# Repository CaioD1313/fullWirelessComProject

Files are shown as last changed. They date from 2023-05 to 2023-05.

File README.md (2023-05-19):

# fullWirelessComProject
Schematics, PCB, Firmwares, DataSheets, Notes and Documentation of this project.

# Full Wireless Communication Device

This project was developed as part of the interview process for the Firmware Engineer position. The objective was to build a Full Wireless Communication Device capable of sending data over a 100m air gap. The repository contains the following components in the main folder/root directory:

- **Datasheets**: This folder contains the datasheets used for the development of the project.
- **Schematics and PCB files**: The "KiCad Projeto Tractian" folder includes the schematics and PCB files related to the project.
- **Firmware**: The "Firmware_fullWirelessSystem" folder contains the firmware code for the device.
- **Technical Documentation**: The project's complete technical documentation can be found in the root directory as the file "Project's Technical Documentation.pdf".

Feel free to explore the respective folders for more details on each aspect of the project.

**Be aware! The documentation is long and tedious, as every technical document should be. (:**

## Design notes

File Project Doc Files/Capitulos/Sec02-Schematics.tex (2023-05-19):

%%%%%%%%%%%%%%%%%%%%%%%%%%%%%%%%%%%%%%%%%%%%%%
%%%%%%%%          Schematics          %%%%%%%%
%%%%%%%%%%%%%%%%%%%%%%%%%%%%%%%%%%%%%%%%%%%%%%

\section{Circuitry}\label{02Sec:Circuitry}

\subsection{Block Diagram}\label{02Sub:BlockDiagram}

The block diagram of the device on the Figure \ref{02fig:BD} consists of several main components that play essential roles in its operation. 
Here is a brief overview of each of these parts:

\begin{itemize}
    \item Microcontroller (ESP8266EX): The ESP8266EX microcontroller is the central component of the device. It is responsible for 
    controlling all operations and functionalities, including wireless communication via WiFi.
    
    \item Program Memory (MX25R3235F): The program memory is where the device's firmware is stored. 
    % In this project, the MX25R3235F 
    % chip with a capacity of 32Mbit was selected. This memory stores the program that controls the device's operation, allowing it 
    % to perform the desired tasks.

    \item Data Memory (AT25SF081): The data memory is used to store the collected data in the device.
    % For this purpose, the 
    % AT25SF081 chip with a capacity of 8Mbit was chosen. This memory is utilized to store the temperature information collected 
    % by the sensor, enabling access and utilization of the data as needed.
    
    \item Temperature Sensor (TMP35): The TMP35 temperature sensor measures the ambient temperature.
    % It was chosen for its low 
    % power consumption, the ability to power off when not in use, good accuracy, and compatibility with other widely used 
    % components in the market, such as the LM35. The temperature sensor provides temperature data that is processed and stored by 
    % the device.

    \item RF Antenna (Texas SWRA117D 2.4GHz - Left): The RF antenna plays a crucial role in the wireless communication of the device. It enables 
    the transmission and reception of radio signals, allowing WiFi communication. The RF antenna ensures a stable and reliable connection between 
    the device and the access point (AP), facilitating the transmission of collected data. More information on this type of PCB antenna can be 
    found at \cite{TexasRFAntenna}.

\end{itemize}

\begin{figure}[H]
    \centering
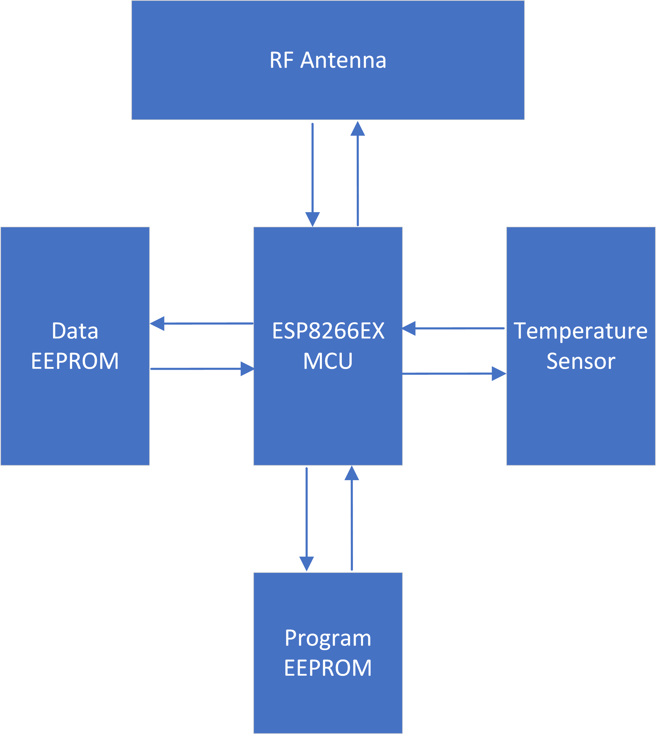
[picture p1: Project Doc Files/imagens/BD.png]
    
    \caption{\textbf{Device's block diagram}.}
    \label{02fig:BD}
\end{figure}

\subsection{Schematics}\label{02Sub:Schematics}

To further delve into the circuit's details, on Figure \ref{02fig:schematics-1} is the schematic diagram of the circuit. It is also divided into 
four blocks, each serving a specific purpose in the device's functionality as follows:

\begin{itemize}
    \item Power Supply Block: The power supply block provides a stable +3.3V voltage to the entire circuit. It ensures 
    that all components receive the necessary power to operate efficiently and reliably. The power supply block includes a 3.7V (mAh to be
    decidade, depending on the longevity needed) and a voltage regulators. Decoupling capacitors and other necessary components to regulate and 
    distribute power are cointained in the ``Main Circuitry'' (see Figure \ref{02fig:schematics-1}).

    \item Program and Data Memory Block: This block encompasses the program and data memories of the device. The program memory, 
    represented by the MX25R3235F chip, stores the firmware responsible for controlling the device's operations. The data memory, 
    represented by the AT25SF081 chip, stores collected data for future transmissions. This block includes the necessary 
    connections between the microcontroller and the memory chips.

    \item Temperature Sensing Block: The temperature sensing block includes the temperature sensor component (TMP35) and its 
    associated circuitry. The sensor measures the ambient temperature and then converts it temperature reading 
    into a eletctrical analog format for processing by the microcontroller. This block is responsible for accurate temperature measurement and 
    data acquisition.

    \item Main Block (Microcontroller and Components): The main block contains the microcontroller (ESP8266EX) and its associated
     components, in addition to the 2.4GHz RF antenna. The microcontroller serves as the central processing unit of the device, executing firmware 
     instructions and coordinating various operations. This block includes components such as crystal oscillators, capacitors, resistors and 
     inductors; these are the supporting elements necessary for the microcontroller's functionality.

\end{itemize}

These four blocks work together to ensure the device's proper operation. The power supply block provides the necessary voltage, 
the program, and data memory block stores and retrieves essential information, the temperature sensing block enables temperature 
measurement. Last but not least, the main block with the microcontroller controls and manages the device's overall functionality.

\begin{landscape}

\begin{figure}[H]
    \centering
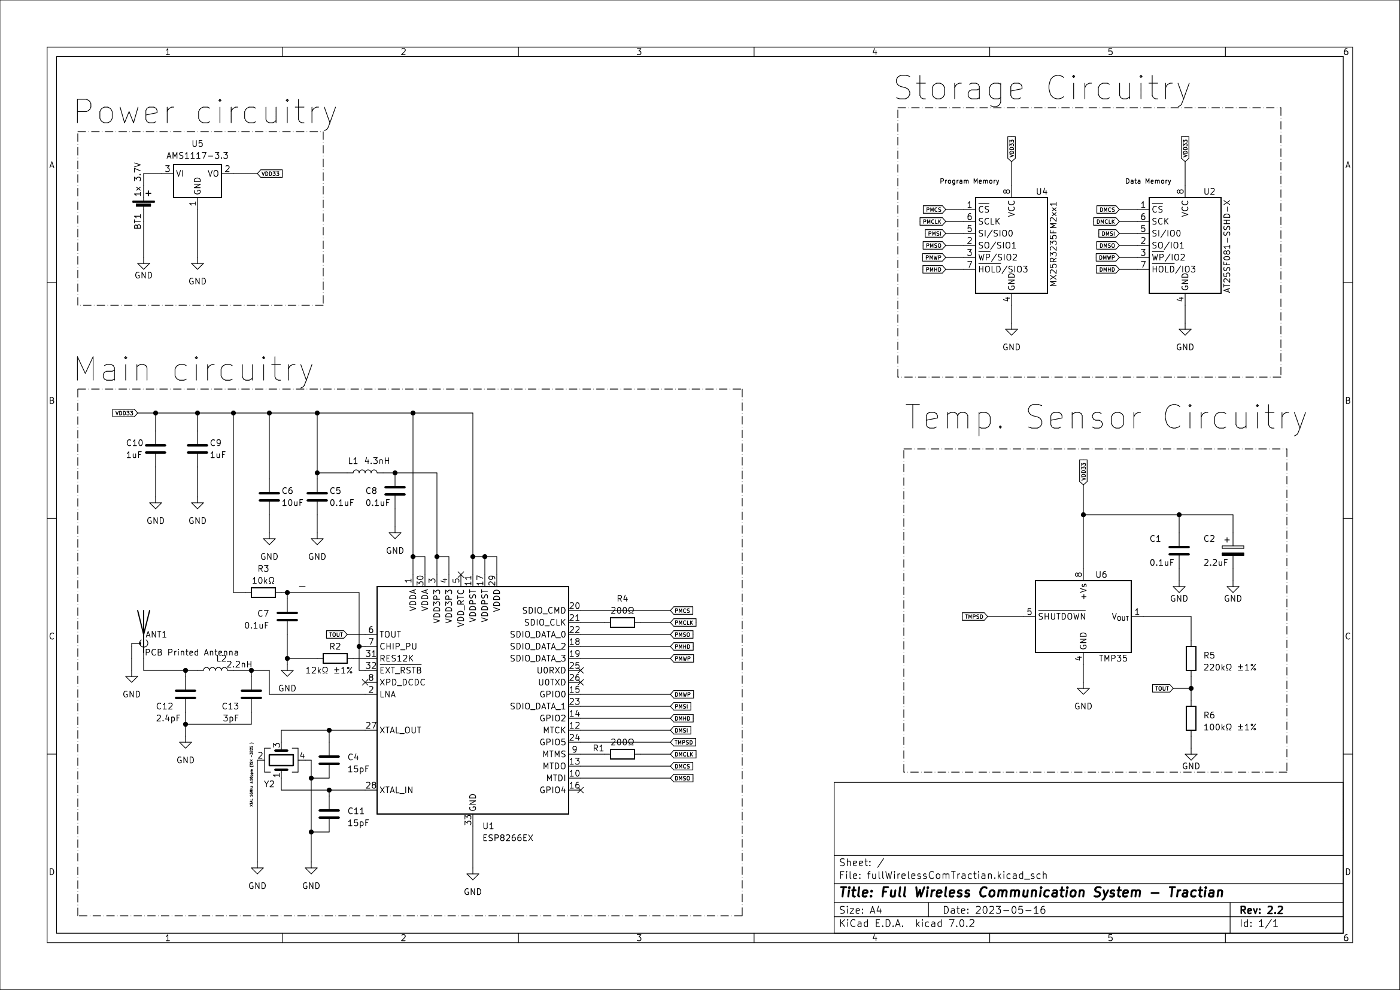
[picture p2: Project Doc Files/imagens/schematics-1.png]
    
    \caption{\textbf{Circuit Schematics}.}
    \label{02fig:schematics-1}
\end{figure}

\end{landscape}

\subsection{Circuit Diagrams}\label{02Sub:CircuitDiagrams}

We start highlitning the main points of the Main Circuitry, putting important
design requirements for the properly function of the ESP8266EX. Most of the references 
were obtained on \cite{ESP8266EX} and \cite{ESP8266HGL}.

\subsubsection{Digital and Analog Supplies Circuitry}\label{02SubSub:DigitalAndAnalogSuppliesCircuitry}

For the analog power supply, ESP8266EX features five analog pins dedicated to power supply, encompassing Pin1, Pin3, and Pin4, 
which specifically cater to the power requirements of the internal PA and LNA. Furthermore, Pin29 and Pin30 serve as power inputs for the internal PLL. 
The acceptable voltage range for these analog power supply pins spans from 2.5 V to 3.6 V \cite{ESP8266HGL}.  \\ 

As for the digital power suplly, ESP8266EX is equipped with two digital pins, namely Pin11 and Pin17, 
dedicated to power supply. When it comes to the digital power supply, the inclusion of supplementary filter capacitors 
is unnecessary. The operational voltage range for the digital power supply pins spans from 1.8 V to 3.3 V \cite{ESP8266HGL}
Both Analog and Digital power supply connections can be seen on Figure \ref{02fig:analogAndDigitalSupplies1}

\begin{figure}[H]
    \centering
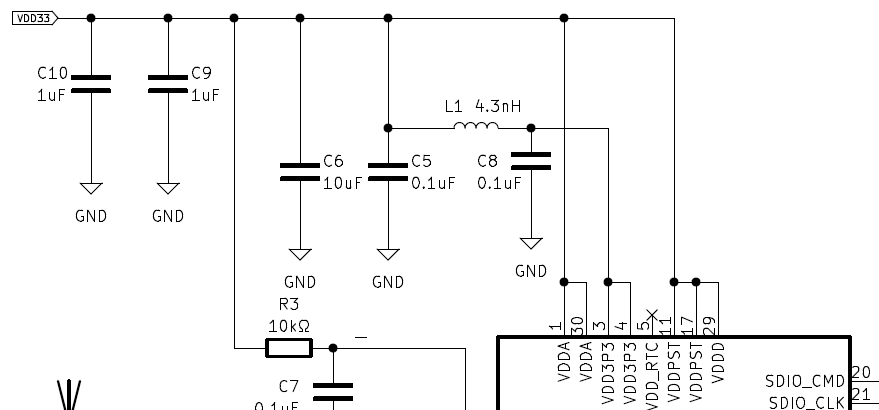
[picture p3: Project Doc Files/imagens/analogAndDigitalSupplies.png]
    
    \caption{\textbf{Digital and Analog Supplies Circuitry}.}
    \label{02fig:analogAndDigitalSupplies1}
\end{figure}

\subsubsection{RC Delay Reset Circuitry}\label{02SubSub:RCDelayResetCircuitry}

The reset pin of ESP8266EX is denoted as Pin32 EXT\_RSTB and plays a vital role in the device's 
operation \cite{ESP8266HGL}. This pin possesses an internal pullup resistor and operates on an active low mechanism. 
As for Pin7 CHIP\_EN, it functions as the enable pin for ESP8266EX. When held at a low state, ESP8266EX powers 
off \cite{ESP8266HGL}.  
Its connections can see on the Figure \ref{02SubSub:RCDelayResetCircuitry}
shwon in the section (\ref{02SubSub:12kOhmRes}) below.

\subsubsection{12Kohm RES}\label{02SubSub:12kOhmRes}

An external GND 12k$\Omega$ showed on Figure \ref{02SubSub:RCDelayResetCircuitry} resistor should be connected with the ERS12K pin 
(pin 31) \cite{ESP8266HGL}. This component must have high accuracy when controlling the bias current. For this,
a 12k$\Omega \pm 1\%$ is required.

\begin{figure}[H]
    \centering
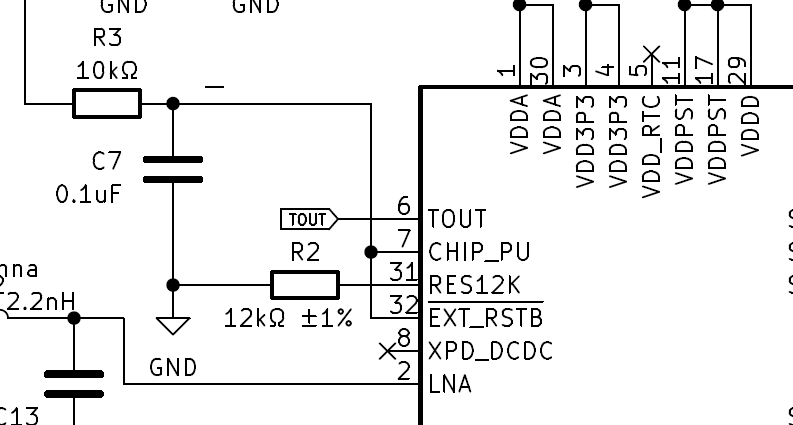
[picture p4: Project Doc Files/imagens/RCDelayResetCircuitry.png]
    
    \caption{\textbf{RC Delay Reset circuitry and 12K RES Pin}.}
    \label{02fig:RCDelayResetCircuitry}
\end{figure}

\subsubsection{RF Antenna Circuitry}\label{02SubSub:RFAntennaCircuitry}

For the 2.4Ghz RF antenna, in terms of ``abstract'' circuit itself, the only requirements is that the
the impedance at the output terminal of the ESP8266 power amplifier is $39 + j6 \Omega$, which necessitates a corresponding 
matched impedance of $39-j6 \Omega$ (from the antenna to the chip). Moreover, for the RF PCB design, a 50$\Omega$ impedance is required
on the track design. For such implementation,
see the Figure \ref{02fig:RFAntennaCircuitry} below (also, see the section \ref{03Sub:RFAntenna}).

\begin{figure}[H]
    \centering
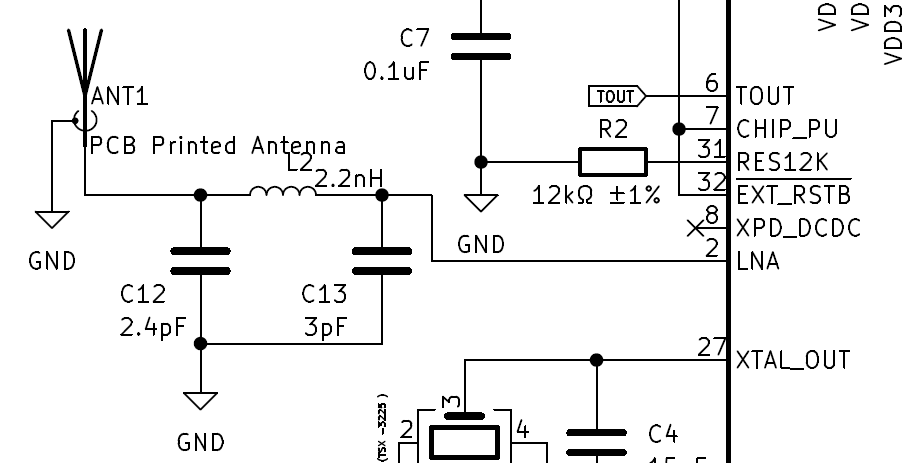
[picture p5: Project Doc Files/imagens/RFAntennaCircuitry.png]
    
    \caption{\textbf{2.4GHz Antenna circuitry}.}
    \label{02fig:RFAntennaCircuitry}
\end{figure}

\subsubsection{XTAL Circuitry}\label{02SubSub:XTALCircuitry}

ESP8266EX has the capability to support crystal oscillators with frequencies of 40 MHz, 26 MHz, and 24 MHz. 
In the circuit design, capacitors C4 and C11 are connected to the ground and added to the input and output terminals 
of the crystal oscillator, respectively. The values of these capacitors can be varied within a range of 6 pF to 22 pF -
15pF was chosen. It is crucial that the crystal oscillator used has a precision of 
$\pm$10 PPM (parts per million) to maintain accurate timing and synchronization. For the XTAL chip, the FA238 (26Mhz)
From Seiko Epson Corporation was chosen \cite{FA238}. The electrical connection for the crystal oscillator is shown
in Figure \ref{02fig:XTALCircuitry}.

\begin{figure}[H]
    \centering
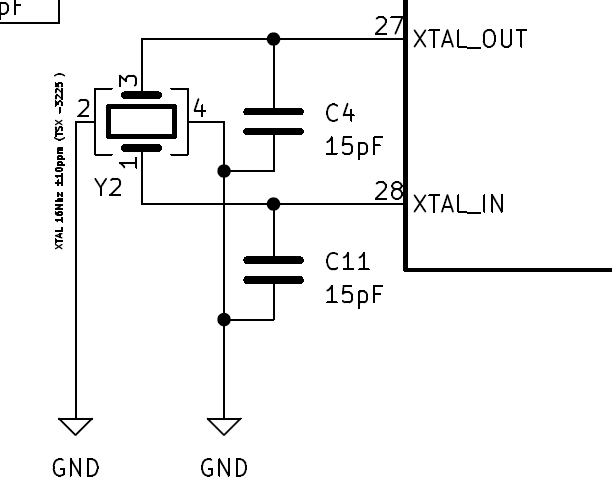
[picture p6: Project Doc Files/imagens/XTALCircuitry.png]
    
    \caption{\textbf{Crystal Oscillator Circuitry}.}
    \label{02fig:XTALCircuitry}
\end{figure}

\subsubsection{Drive Current Serial Clock RES}\label{02SubSub:DriveCurrentSerialClockRES}

To reduce drive current and eliminates external interruptions, a 200 $\Omega$ is connected to the flashs 
(Pin21 SD\_CLK and Pin9 MTMS). It is recommended a 0402 resistor package \cite{ESP8266HGL}.

\begin{figure}[H]
    \centering
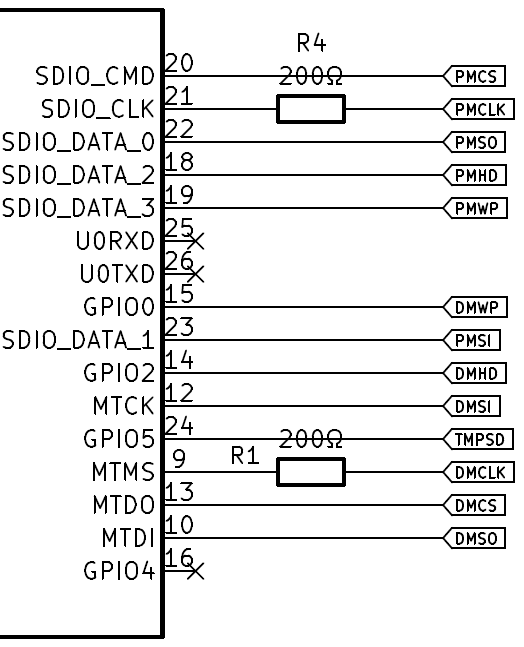
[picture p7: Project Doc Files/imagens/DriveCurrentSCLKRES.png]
    
    \caption{\textbf{200$\Omega$ RES Drive Current}.}
    \label{02fig:DriveCurrentSCLKRES}
\end{figure}

As for the Nets connected on each of the pins shown in Figure \ref{02fig:DriveCurrentSCLKRES},
``P'' stands for ``Program'', ``D'' is ``Data'', ``SI'' and ``SO'' are ``Serial IN'' (MOSI) and
``Serial Out'' (MISO) respectivily (notice the ``IN'' ``Out'' refers to the slave pins). Moreover,
``SCLK'' means ``Serial Clock'', ``WP'' is ``Write Protect', ``HD'' refers to ``Hold''.
Finnaly, ``TEMPSD'' stands for ``TMP 35 Shutdown''. So, for instance, ``DMCLK''
refers to the ``Data Memory Serial Clock'' Net. From this point, the rest of the 
blocks are described.

\subsubsection{Power Circuitry}\label{02SubSub:PowerCircuitry}

For the power circuitry, a 3.7V battery is used, along with a voltage regulator.
The AMS1117 \cite{AMS1117} for 3.3V integrated circuit (IC) was utilized to ensure protection and integrity of 
the power supply.

\begin{figure}[H]
    \centering
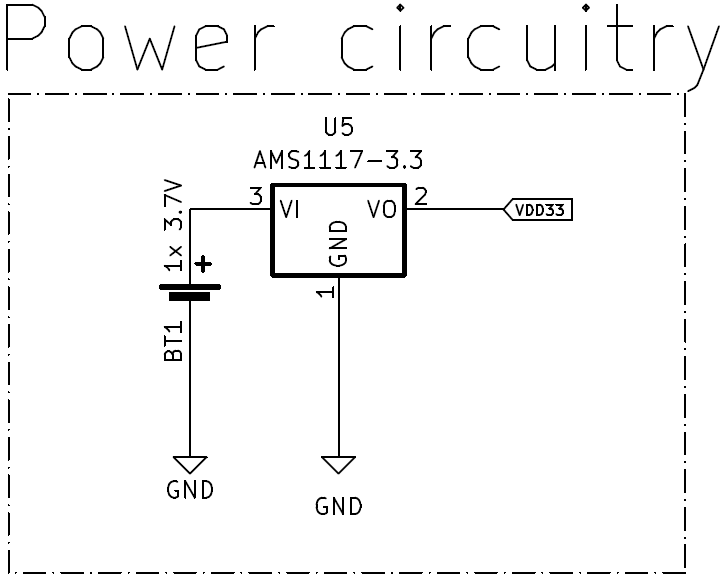
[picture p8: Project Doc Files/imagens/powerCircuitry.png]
    
    \caption{\textbf{3.3V Power circuitry}.}
    \label{02fig:powerCircuitry}
\end{figure}

\subsubsection{Storage Circuitry}\label{02SubSub:StorageCircuitry}

As for the program memory, since there is no internal memory available, an external flash memory is required for the ESP8266EX to store the user 
program. It is important to consider that the minimum capacity of the memory should be 512kB for disabled OTA (firmware updates Over The Air) or 1MB 
for enabled OTA. For firmware programming into the memory, the ESP8266EX supports Standard SPI, Dual SPI, and Quad SPI, which need to be selected prior 
to the programming process. The chosen memory, MX25R3235F \cite{ProgramMemoryMX}, meets all the aforementioned requirements. \\

For the data memory, the requirements essentially boil down to having sufficient space (min 500kB) and supporting SPI communication. The chosen IC, 
AT25SF081 \cite{DataMemoryAT}, fulfills these requirements. Additionally, this IC allows for serial data traffic on its I/Os at speeds of up to 50MHz 
(85MHz and 104MHz in specific cases). Since the communication with this chip was achieved through bit banging (see section \ref{04Sub:FeaturesAndAlgorithms}
), with an SCLK oscillation period of 6$\mu s$, \textit{i.e.}, a frequency of $f = $ 166.666kHz, operating with this chip is entirely feasible, obviating the 
need for hardware-based SPI interface. Furthermore, The protection bits are set to zero by default \cite{DataMemoryAT}, and there is no need to modify these bits. 
Therefore, the memory can be programmed and erased without any difficulties. Both program and data memory can be seen on Figure 
\ref{02fig:storageCircuitry}

\begin{figure}[H]
    \centering
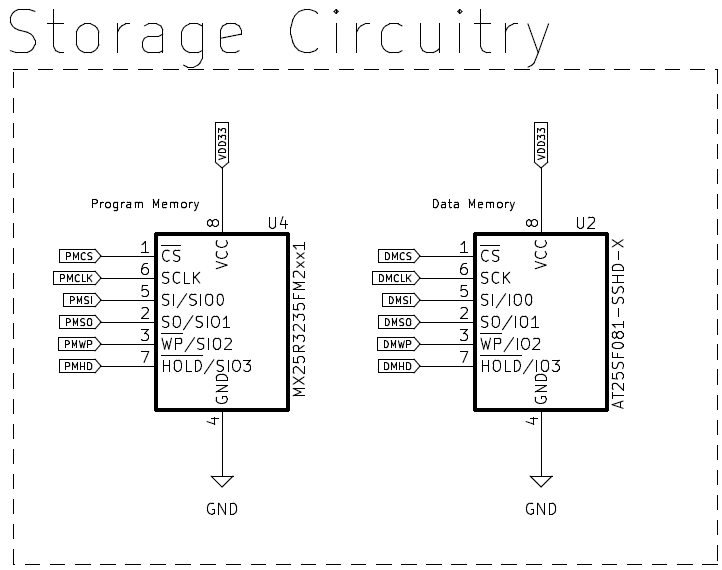
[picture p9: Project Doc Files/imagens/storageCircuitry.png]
    
    \caption{\textbf{Storage circuitry - Program and Data Memory}.}
    \label{02fig:storageCircuitry}
\end{figure}

\subsubsection{Temperature Sensor Circuitry}\label{02SubSub:TemperatureSensorCircuitry}

The TMP35 temperature sensor \cite{TMP35} provides analog temperature readings, which can be converted into temperature values using appropriate 
calibration by ``voltage divider circuit'' shown in the Figure \ref{02fig:temperatureSensorCircuitry}. This adjustment is need as the 
ESP8266EX ADC Input can only receive values between 0 and 1V \cite{ESP8266EX}.

\begin{figure}[H]
    \centering
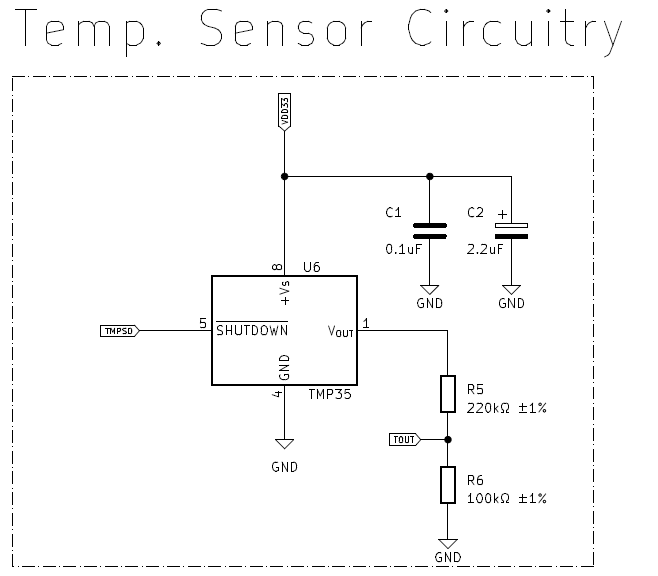
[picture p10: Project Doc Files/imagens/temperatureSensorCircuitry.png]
    
    \caption{\textbf{Temperature measuring circuitry}.}
    \label{02fig:temperatureSensorCircuitry}
\end{figure}

%%%%%%%%%%%%%%%%%%%  END  %%%%%%%%%%%%%%%%%%%%
%%%%%%%%          Schematics          %%%%%%%%
%%%%%%%%%%%%%%%%%%%%%%%%%%%%%%%%%%%%%%%%%%%%%%

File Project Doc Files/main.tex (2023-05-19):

%\documentclass{article}
%\documentclass[11pt,openany,brazil]{report}
\documentclass[12pt,brazil]{article}

%%%%%%%%%%%%%%%%%%%%%%%%%%%%%%%%%%%%%%%
%%%%%%% Pacotes de formatação: %%%%%%%%
%%%%%%%%%%%%%%%%%%%%%%%%%%%%%%%%%%%%%%%

\usepackage[utf8]{inputenc} % indica o uso dos caracteres da nossa língua
\usepackage[english]{babel} % indica que o texto está em português, assim atributos
                               % automáticos, tais como criação de capítulos, inserção de
                               % elementos no sumário e etc já são escritos em pt-br

\usepackage{ragged2e} % fornece o comando \justifying

\usepackage{geometry}
 \geometry{
 a4paper,
 total={170mm,257mm},
 left=20mm,
 top=40mm,
 bottom = 30mm,
 }

% Pacote para formatção e utilização de tabelas
\usepackage{tabularx}
\usepackage{multirow} % permite a mescla de colunas e criação de merges 

\usepackage{array} % pacote para manter tabela com wdith fixa
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
                micros, noInterrupts, noTone, pinMode, pulseIn, pulseInLong, shiftIn, 
                shiftOut, tone, yield, Stream, begin, end, peek, read, print, 
                println, available, availableForWrite, flush, setTimeout, find, 
                findUntil, parseInt, parseFloat, readBytes, readBytesUntil, readString, 
                readStringUntil, trim, toUpperCase, toLowerCase, charAt, compareTo, 
                concat, endsWith, startsWith, equals, equalsIgnoreCase, getBytes, 
                indexOf, lastIndexOf, length, replace, setCharAt, substring, 
                toCharArray, toInt, press, release, releaseAll, accept, click, move, 
                isPressed, isAlphaNumeric, isAlpha, isAscii, isWhitespace, isControl, 
                isDigit, isGraph, isLowerCase, isPrintable, isPunct, isSpace, 
                isUpperCase, isHexadecimalDigit, 
                },      
%
%
  %%% Set Other Colors %%%
  stringstyle=\color{arduinoDarkBlue},    
  commentstyle=\color{arduinoGrey},    
%          
%   
  %%%% Line Numbering %%%%
  numbers=left,                    
  numbersep=5pt,                   
  numberstyle=\color{arduinoGrey},    
  %stepnumber=2,                      % show every 2 line numbers
%
%
  %%%% Code Box Style %%%%
  breaklines=true,                    % wordwrapping
  tabsize=2,         
  basicstyle=\ttfamily  
}

%%%% DEFINIÇÕES DE CORES HTML: NOSSO PADRÃO PARA UTILZIÇÃO NA DOCUMENTAÇÃO

% Padrão -> {NomeDaCor}{PadraoDaCor}{CódigoHexadecimal}

\definecolor{ClassColor}{HTML}{4EC9A7} %Cor das classes do C#
\definecolor{Control}{HTML}{FF6400} % Laranja da Devlean
\definecolor{SF}{HTML}{06428D} % Azul Smart Factory
\definecolor{TabelaBanco}{HTML}{315fbb} % Padrão de cor para tabelas no banco Devlean
\definecolor{IList}{HTML}{DCC774} %Cor das classes do C#
%%%%%%%%%%%%%%%% FIM %%%%%%%%%%%%%%%%%%
%%%%%%%% Pacotes de cores:  %%%%%%%%%%%
%%%%%%%%%%%%%%%%%%%%%%%%%%%%%%%%%%%%%%%

%%%%%%%%%%%%%%%%%%%%%%%%%%%%%%%%%%%%%%%
%%%%%%%% Pacotes para hyperlink %%%%%%%
%%%%%%%        no sumário       %%%%%%%
%%%%%%%%%%%%%%%%%%%%%%%%%%%%%%%%%%%%%%%

\usepackage{hyperref}
\hypersetup{
    colorlinks=true, %set true if you want colored links
    linktoc=all,     %set to all if you want both sections and subsections linked
    linkcolor=black,  %choose some color if you want links to stand out
    filecolor=blue,      
    urlcolor=blue,
    citecolor = black
}

%%%%%%%%%%%%%%%% FIM %%%%%%%%%%%%%%%%%%
%%%%%%%% Pacotes para hyperlink %%%%%%%
%%%%%%%        no sumário       %%%%%%%
%%%%%%%%%%%%%%%%%%%%%%%%%%%%%%%%%%%%%%%

%%%%%%%%%%%%%%%%%%%%%%%%%%%%%%%%%%%%%%%
%%%%%%%% Pacotes para BackGroud %%%%%%%
%%%%%%%        Template         %%%%%%%
%%%%%%%%%%%%%%%%%%%%%%%%%%%%%%%%%%%%%%%

%%%% Se quiser colocar apenas em algumas páginas, utilizar o campo \usepackage[pages=some] 'some' <-
%% Comandos para colocar background
% \BgThispage %% página que contém o background

% \clearpage 
% \usepackage[pages=all]{background}

% \backgroundsetup{
% scale=1,
% color=black,
% opacity=1,
% angle=0,
% contents={%
%   \includegraphics[width=\paperwidth,height=\paperheight]{imagens/templatePlataformaInovacao.png}
%   }%
% }

%%%%%%%%%%%%%%%% FIM %%%%%%%%%%%%%%%%%%
%%%%%%%% Pacotes para BackGroud %%%%%%%
%%%%%%%        Template         %%%%%%%
%%%%%%%%%%%%%%%%%%%%%%%%%%%%%%%%%%%%%%%

% %%%%%%%%%%%%%%%%%%%%%%%%%%%%%%%%%%%%%%%
% %%%%%%%   Pacotes para Fonte    %%%%%%%
% %%%%%%%        Arial            %%%%%%%
% %%%%%%%%%%%%%%%%%%%%%%%%%%%%%%%%%%%%%%%

% \usepackage{uarial}
% \setmainfont{Arial}

% %%%%%%%%%%%%%%%% FIM %%%%%%%%%%%%%%%%%%
% %%%%%%%   Pacotes para Fonte    %%%%%%%
% %%%%%%%        Arial            %%%%%%%
% %%%%%%%%%%%%%%%%%%%%%%%%%%%%%%%%%%%%%%%

\renewcommand*\footnoterule{}

%%%%%%%%%%%%%%%%%%%%%%%%%%%%%%%%%%%%%%%
%%%%%%%%% INÍCIO DOCUMENTO  %%%%%%%%%%%
%%%%%%%%%%%%%%%%%%%%%%%%%%%%%%%%%%%%%%%
\renewcommand{\thefootnote}{\Roman{footnote}}
\begin{document}

%%%%%%%%%%%%%%%%%%%%%%%%%%%%%%%%%%%%%%%
%%%%%%%   Capa do Documento     %%%%%%%
%%%%%%%%%%%%%%%%%%%%%%%%%%%%%%%%%%%%%%%

\pagenumbering{gobble}  

\begin{phantom}
A \vspace{6cm}
\end{phantom}

\begin{center}
    \Huge \textbf{Full Wireless Communication Device}\vspace{8cm}
\end{center} 

\begin{center}
    \raggedleft{\large \textbf{Project documentation.} }  \vspace{4cm}
\end{center} 

\begin{center}
    \raggedleft{\textbf{Caio Dutra} } 
\end{center} 

\begin{center}
    \raggedleft{\textbf{May 2023} } \\ 
\end{center} 

%%%%%%%%%%%%%%%   FIM   %%%%%%%%%%%%%%%
%%%%%%%   Capa do Documento     %%%%%%%
%%%%%%%%%%%%%%%%%%%%%%%%%%%%%%%%%%%%%%%

%%%%%%%%%%%%%%%%%%%%%%%%%%%%%%%%%%%%%%
%%%%%% Sumário do Documento     %%%%%%
%%%%%%%%%%%%%%%%%%%%%%%%%%%%%%%%%%%%%%
\justifying
\newpage
\tableofcontents %cria sumário

\clearpage % Comando para tirar a numeração de uma página 
           % Nesse caso -> Sumário (Tabel of contents)

%%%%%%%%%%%%%%%%%%%%%%%%%%%%%%%%%%%%%%
%%%%%% Sumário do Documento     %%%%%%
%%%%%%%%%%%%%%%%%%%%%%%%%%%%%%%%%%%%%%

%%%%%%%%%%%%%%%%%%%%%%%%%%%
% Aqui começa a paginação %
%%%%%%%%%%%%%%%%%%%%%%%%%%%

%%%%%%%%%%%%%%%%%%%%%%%%%%
% Aqui acaba a paginação %
%%%%%%%%%%%%%%%%%%%%%%%%%%

%%%%%%%%%%%%%%%%%%%%%%%%%%%%%%%
% Inicialização dos Capítulos %
%%%%%%%%%%%%%%%%%%%%%%%%%%%%%%%

%%%%%%%%%%%%%%%%%%%%%%%%%%%%%%%%%%%%%%%%
%%%   Sec 00   -  Preliminaries      %%%
%%%%%%%%%%%%%%%%%%%%%%%%%%%%%%%%%%%%%%%%

\input{Capitulos/Sec00-Preliminaries}

%%%%%%%%%%%%%%%   FIM  %%%%%%%%%%%%%%%%%
%%%   Sec 00   -  Preliminaries      %%%
%%%%%%%%%%%%%%%%%%%%%%%%%%%%%%%%%%%%%%%%

%%%%%% Esta linha retira a numeração das páginas
\pagenumbering{gobble}

%%%%%% Estas duas linhas fazem a numeração das páginas
\pagenumbering{arabic}
\setcounter{page}{1}
%%%%%%

%%%%%%%%%%%%%%%%%%%%%%%%%%%%%%%%%%%%%%%%
%%%   Sec 01   -   Introduction      %%%
%%%%%%%%%%%%%%%%%%%%%%%%%%%%%%%%%%%%%%%%

\input{Capitulos/Sec01-Intro.tex}

%%%%%%%%%%%%%%%   FIM  %%%%%%%%%%%%%%%%%
%%%   Sec 01   -   Introduction      %%%
%%%%%%%%%%%%%%%%%%%%%%%%%%%%%%%%%%%%%%%%

%%%%%%%%%%%%%%%%%%%%%%%%%%%%%%%%%%%%%%%%%%%%%%%%%%%%%%%%%
%%%   Sec 02   -       Schematics                     %%%
%%%%%%%%%%%%%%%%%%%%%%%%%%%%%%%%%%%%%%%%%%%%%%%%%%%%%%%%%

\input{Capitulos/Sec02-Schematics.tex}

%%%%%%%%%%%%%%%           FIM          %%%%%%%%%%%%%%%%%%
%%%   Sec 02   -       Schematics                     %%%
%%%%%%%%%%%%%%%%%%%%%%%%%%%%%%%%%%%%%%%%%%%%%%%%%%%%%%%%%

%%%%%%%%%%%%%%%%%%%%%%%%%%%%%%%%%%%%%%%%%%%%%%%%%%%%%%%%%%%%%%
%%%   Sec 03   -            PCB                            %%%
%%%%%%%%%%%%%%%%%%%%%%%%%%%%%%%%%%%%%%%%%%%%%%%%%%%%%%%%%%%%%%

\input{Capitulos/Sec03-PCB.tex}

%%%%%%%%%%%%%%%             FIM             %%%%%%%%%%%%%%%%%%
%%%   Sec 03   -            PCB                            %%%
%%%%%%%%%%%%%%%%%%%%%%%%%%%%%%%%%%%%%%%%%%%%%%%%%%%%%%%%%%%%%%

%%%%%%%%%%%%%%%%%%%%%%%%%%%%%%%%%%%%%%%%%%%%%%%%%%%%%%%%%
%%%   Sec 04   -        Firmware                      %%%
%%%%%%%%%%%%%%%%%%%%%%%%%%%%%%%%%%%%%%%%%%%%%%%%%%%%%%%%%

\input{Capitulos/Sec04-Firmware.tex}

%%%%%%%%%%%%%%%           FIM          %%%%%%%%%%%%%%%%%%
%%%   Sec 04   -        Firmware                      %%%
%%%%%%%%%%%%%%%%%%%%%%%%%%%%%%%%%%%%%%%%%%%%%%%%%%%%%%%%%

\counterwithin{subsection}{section}

%%%%%%%%%%%%%%%%%%%%%%%%%%%%%%%
%  Finalização dos Capítulos  %
%%%%%%%%%%%%%%%%%%%%%%%%%%%%%%%

\newpage

%Comando para o package{natbib}
%\bibliography{bibliografia}

%Comando para o package{biblatex}
\clearpage
\phantomsection
\addtocontents{toc}{\protect\renewcommand{\protect\cftsecleader}{\protect\cftdotfill{\protect\cftdotsep}}}
\addcontentsline{toc}{section}{\protect\numberline{}References}
\addtocontents{toc}{\cftpagenumbersoff{section}}
\addtocontents{toc}{\cftpagenumberson{section}}

\printbibliography

\end{document}

%%%%%%%%%%%%%%%%%%%%%%%%%%%%%%%%%%%%%%%
%%%%%%%%%   FIM DOCUMENTO   %%%%%%%%%%%
%%%%%%%%%%%%%%%%%%%%%%%%%%%%%%%%%%%%%%%

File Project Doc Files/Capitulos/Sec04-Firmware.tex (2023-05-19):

\newpage
%%%%%%%%%%%%%%%%%%%%%%%%%%%%%%%%%%%%
%%%%%%%%      Firmware      %%%%%%%%
%%%%%%%%%%%%%%%%%%%%%%%%%%%%%%%%%%%%

\section{Firmware}\label{04Sec:Firmware}

\subsection{Firmware Description}\label{04Sub:FirmwareDescription}

The ultimate goal of this firmware is to establish a complete wireless communication 
between a data collecting station (ESP8266EX) and an access point located 100m away 
using the WiFi protocol. The hardware collects data on-site, stores it with a size of 500kB, 
and then sends it to the access point. \\ 

For the purpose of data collection, a temperature measuring circuit was implemented
on the hardware using a TMP36 IC. A linear time-invariant system, namely the Moving 
Average Filter, is required to ensure that the measured temperature remains in a stable
state when it is saved in the flash data memory integrated into the hardware. \\ 

For the WiFi protocol, the library "ESP8266WiFi.h" was used. \\

For the communication between the microcontroller and the Flash Data Memory, it is used the SPI 
communication protocol.

\subsection{Configurations and Parameters}\label{04Sub: ConfigurationsAndParameters}

The code includes various configurations and parameters for an ESP8266 program involving SPI communication, temperature reading, 
and Wi-Fi transmission. These parameters are the following. \\ 

The $<$ESP8266WiFi.h$>$ library is a header file specific to the ESP8266 platform. It provides the necessary functions and definitions to enable 
Wi-Fi connectivity and communication on the ESP8266 module. This library allows the program to connect to Wi-Fi networks, perform 
network-related operations, and establish connections with hosts over the network.

WiFiClient \_hostClient instance:

\begin{itemize}
    \item The WiFiClient \_hostClient; creates an instance of the WiFiClient class named \_hostClient. The WiFiClient class is part of the 
    ESP8266WiFi library and represents a client connection in a Wi-Fi network. In this case, \_hostClient is used to establish a connection with 
    the host specified in the code (HOST). It will be responsible for handling the communication between the ESP8266 and the host, enabling data 
    transmission over the established connection.
\end{itemize}

By creating an instance of WiFiClient, the program can make use of its methods and functionalities to connect to a host and exchange data.

\noindent GPIOs for SPI communication with data memory:

\begin{itemize}
    \item DMCS: Data Memory Chip/Slave Select, set to 15 (GPIO15).
    \item DMCLK: Data Memory Serial Clock, set to 14 (GPIO14).
    \item DMSI: Data Memory SI (slave data input) (MOSI), set to 13 (GPIO13).
    \item DMSO: Data Memory SO (slave data output) (MISO), set to 12 (GPIO12).
    \item DMWP: Data Memory Write Protect, set to 0 (GPIO0).
    \item DMHD: Data Memory Hold, set to 2 (GPIO2).
\end{itemize}

SPI delay for 8 MHz communication:

\begin{itemize}
    \item Half\_SPI\_Period: delay period for SPI communication in microseconds, set to 3. This corresponds to a frequency of approximately 166.666 kHz.
\end{itemize}

Temperature sensor GPIO definitions:

\begin{itemize}
    \item Temp\_Sensor\_ADC\_Pin: analog input pin (ADC) for TMP35 sensor output, set to 17.
    \item Temp\_Sensor\_Shutdown\_Pin: shutdown pin (SHUTDOWN) for TMP35 sensor, set to 5 (GPIO5).
\end{itemize}

Network settings:

\begin{itemize}
    \item SSID: Service Set Identifier (SSID) of the Wi-Fi network to be connected, set to "Fake\_WiFi\_Net\_To\_Connect".
    \item PSSWRD: Password of the Wi-Fi network to be connected, set to "Fake\_WiFi\_Net\_Password".
    \item HOST: Fake URL to send data, set to "192.13.14.5/temperature\_log\_files". It is assumed to be used for sending a 500 kB file.
    \item \_httpPort: HTTP port to be used, set to 80.
\end{itemize}

Arrays and variables related to temperature data reading and sending:

\begin{itemize}
    \item Temp\_Vector: byte array that stores 256 samples of stable temperature measurements.
    \item Temp\_Buffer: buffer to store 50 samples of instantaneous temperature readings.
    \item \_addressBytes: byte array with 3 bytes for memory address.
    \item \_readData: byte array used to read 1 kB of information from data memory and send it to the host.
    \item ADDRESS: starting memory address for writing, set to 0x000000.
    \item \_packetCount: counter for packets sent to the host.
    \item \_numOfTries: counter for the number of connection attempts to the host before giving up and collecting another set of temperature values.
    \item  p: counter for the 500 kB file (counts the number of 1024-byte packets sent to the host).
    \item q: counter for the 1024 bytes to be sent in \_readData.
\end{itemize}

\noindent \textbf{The actual code for this configurations are shown bellow:}

\begin{lstlisting}[language=Arduino]

#include <ESP8266WiFi.h>

WiFiClient _hostClient; // creates an instance of WifiClient for the host to be connected

// Data Memory GPIO's definitions for SPI comm:
#define DMCS 15 // Data Memory Chip/Slave Select - Pin 13 on ESP8266EX -> (MTDO) GPIO15
#define DMCLK 14 // Data Memory Serial Clock - Pin 9 on ESP8266EX -> (MTMS) GPIO14
#define DMSI 13 // Data Memory SI (slave data input) (MOSI) - Pin 12 on ESP8266EX -> (MTCK) GPIO13
#define DMSO 12 // Data Memory SO (slave data output) (MISO) - Pin 10 on ESP8266EX -> (MTDI) GPIO12
#define DMWP 0 // Data Memory Write Protect - Pin 15 on ESP8266EX -> (GPIO0) GPIO0
#define DMHD 2 // Data Memory Hold - Pin 14 on ESP8266EX -> (GPIO2) GPIO2

// SPI delay for 8Mhz comm (Flash Data Memory operates up to 8Mhz for single IO mode)
// For we are using bit banging data, a (way) lower frequency will be used.
// Acording to Arduino Reference, for 'delayMicroseconds(t);' operates very accurately 
// for a minimum valeu of t = 3 (3us). Being so, The period of the SCLK shall be 6us,
// which leads to f = 166.666 kHz. That being said, every 3 seconds or so 500,000
// samples of temperature will be collected. This barely has any practical uses,
// but the principle of the challenge stands.
#define Half_SPI_Period 3 // for f = 8MHz , T = 6us

// Temperature Sensor GPIO definition
#define Temp_Sensor_ADC_Pin 17 // TMP35 Vout - Pin 6 on ESP8266EX -> (TOUT) ADC_in | On NodeMCU it is mapped to pin 17
#define Temp_Sensor_Shutdown_Pin 5 // TMP35 SHUTDOWN - Pin 24 on ESP8266EX -> (GPIO5) GPIO5

const char* SSID = "Fake_WiFi_Net_To_Connect"; // service set identifier of the AP to be connected

const char* PSSWRD = "Fake_WiFi_Net_Password"; // net password of the AP to be connected

const char* HOST = "192.13.14.5/temperature_log_files"; // Fake URL to send data (500kB file)

const int _httpPort = 80; // HTTP Port to be used

// Global Array to store 256 Stable Temperature Readings (later to be used on Data Memory Write)
byte Temp_Vector[256]; // records 256 sample of stables temp measurements to record on a page on Data Memory
byte Temp_Buffer[50]; // Buffer to stores 50 samples of intantaneous Temperature readings

// 3Byte Memory Address
byte _addressBytes[3];

// 1024 array for reading from data memory and sending via WiFi (total of 500 packets of 1024 bytes to be sent -> 500kB)
byte _readData[1024];

// Memory Address Word
unsigned long ADDRESS = 0x000000; // By our definition, Memory Write starts at address 0
int _packetCount = 0; // count var for Page Program

int _numOfTries = 0; // starts with 0 - count the number of times the station tried to connect with to host before it gives up and leads to another set of collecting tempereture values
// int _connectionSuccess; // indicates if the connection to the host was sucessful (1) or not (0)

int p; // count var for 500kB file (counts the number os 1024bytes packets sent to the host - total of 512,000 bytes)
int q; //count var (parameter of _readData) for 1024 bytes to be sent

\end{lstlisting}

\subsection{Firmware Architecture}\label{04Sub:FirmwareArchitecture}

At a high level, the code operates with the following flowchart to outline its functionality. 
First, it performs a setup process to initialize necessary variables and configurations. Then, it enters 
the main loop where it activates the temperature sensor, collects temperature data, and stores it in memory. Afterward,
 it turns off the temperature sensor. Next, it attempts to establish a connection with the designated Wi-Fi Access Point 
 (AP). If successful, it tries to connect to the host URL, allowing for a maximum of 10 connection attempts. If the 
 connection is established, it sends the collected temperature data to the host. Finally, regardless of the connection 
 utcome, the code disconnects from the host and returns to the beginning of the main loop to repeat the process. This 
 flowchart provides a high-level overview of the code's functionality and the sequential steps it follows to achieve its 
 intended purpose.

\begin{figure}[H]
    \centering
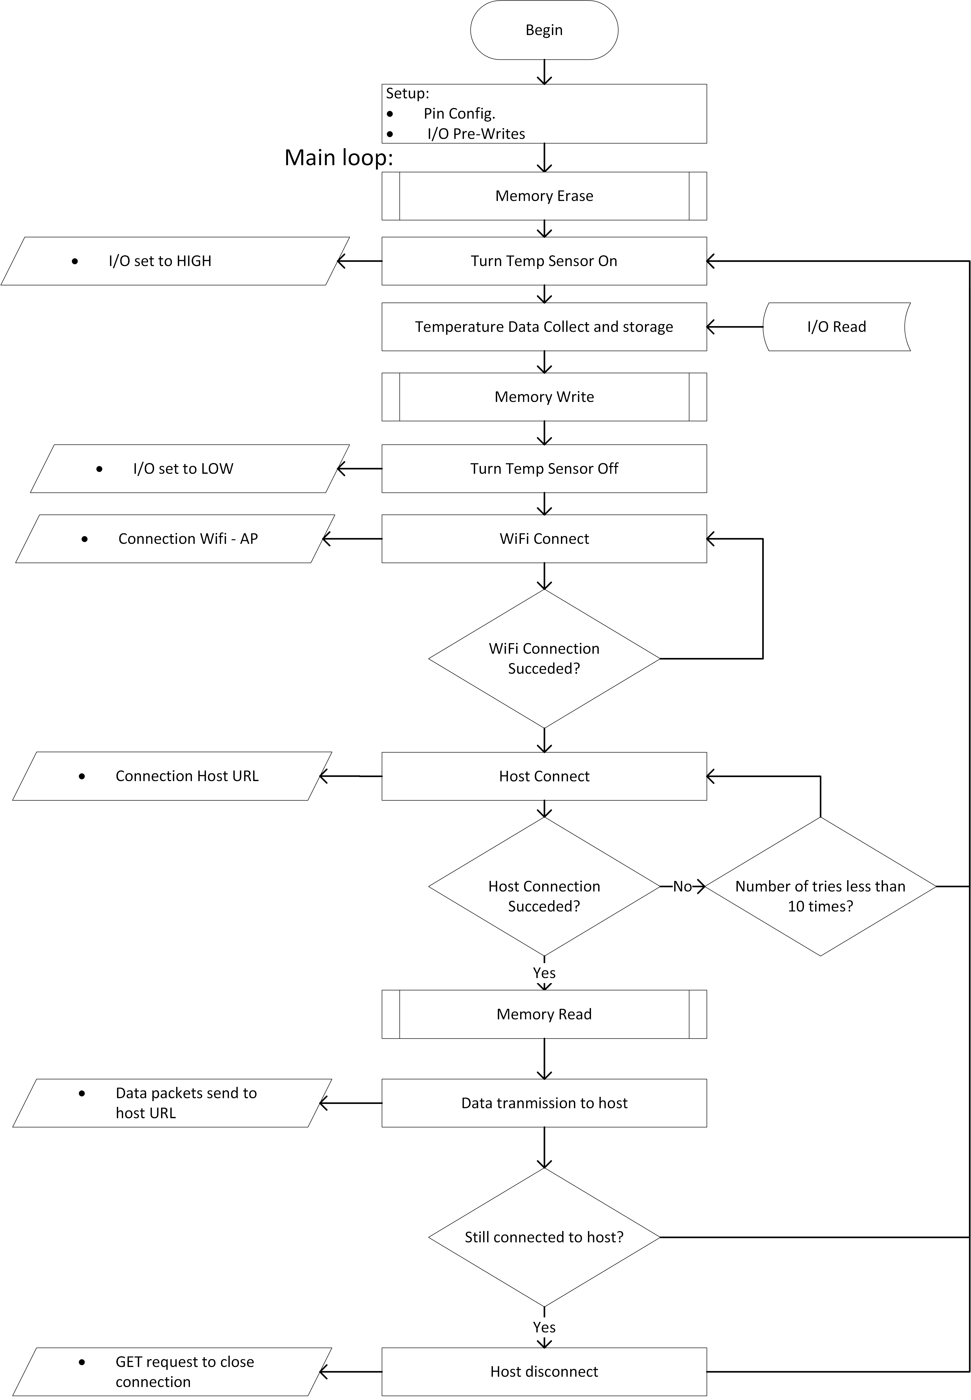
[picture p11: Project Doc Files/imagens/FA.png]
    
    \caption{\textbf{High level overview of the firmware}.}
    \label{02fig:FA}
\end{figure}

\subsection{Features and Algorithms}\label{04Sub:FeaturesAndAlgorithms}

In order to stabilize the instantaneous temperature readings, an Moving Average Filter Algorithm was implemented in the 
project. This algorithm takes a series of temperature measurements and calculates their average over a specified window of 
time or number of samples. By smoothing out variations and fluctuations in the temperature data, the Moving Average Filter 
Algorithm helps to provide a more stable and reliable temperature reading. \\ 

Additionally, as part of a possible future implementation, a general 3-byte array generator algorithm was implemented. This 
algorithm takes a long variable in the form of six nibbles "0xXYZWTR" as input. It then extracts and organizes the individual 
nibbles of the long variable into a 3-byte array. This allows for efficient storage and manipulation of the long variable in 
byte-based operations. The 3-byte array representation offers flexibility for future use, such as data transmission, storage, 
or further processing, depending on the project's requirements. \\ 

In addition to the mentioned components, the project also incorporates subroutines for Data Memory operations, 
including Write, Read, and Erase functionalities. These subroutines enable the program to interact with the Data Memory 
module connected to the ESP8266. The Write subroutine facilitates the storage of data, such as temperature readings or other 
relevant information, into the Data Memory. The Read subroutine allows retrieving data from the Data Memory, enabling access 
to previously stored information. Lastly, the Erase subroutine provides a mechanism to clear or reset the Data Memory, erasing 
any existing data stored within it. By implementing these subroutines, the project gains the capability to effectively manage 
and manipulate data in the Data Memory module, facilitating data logging, analysis, or further processing as required.

\subsection{Interfaces and Protocols}\label{04Sub: InterfacesAndProtocols}

In the project, a routine for SPI communication using bit banging was implemented. This approach allows direct control over 
the individual signal lines involved in the SPI protocol. The SPI protocol is widely used for communication between 
microcontrollers and peripheral devices such as the data memory chip in this case. The implemented routine operates on Mode 0, 
which is accepted by the data memory chip. Mode 0 means that the clock signal is idle low, and data is sampled on the leading 
edge of the clock signal. \\ 

The SPI communication routine has a clock period of 6 microseconds (6$\mu s$), resulting in a frequency of approximately 
166,666 kHz. This frequency falls within the acceptable range supported by the memory IC, ensuring reliable and efficient data 
transfer. By utilizing bit banging and adhering to the Mode 0 protocol with an appropriate clock frequency, the implemented 
routine enables effective communication between the ESP8266 and the data memory chip, facilitating data read/write operations 
and supporting the overall functionality of the project. \\ 

%%%%%%%%%%%%%    END   %%%%%%%%%%%%%
%%%%%%%%      Firmware      %%%%%%%%
%%%%%%%%%%%%%%%%%%%%%%%%%%%%%%%%%%%%

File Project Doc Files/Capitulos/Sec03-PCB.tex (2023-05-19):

\newpage
%%%%%%%%%%%%%%%%%%%%%%%%%%%%%%%%%%%%
%%%%%%%%        PCB         %%%%%%%%
%%%%%%%%%%%%%%%%%%%%%%%%%%%%%%%%%%%%

\section{Printed Circuit Board}\label{03Sec:PCB}

\subsection{PCB Design}\label{03Sub:PCBDesign}

\subsection{PCB Specifications}\label{03Sub:PCBSpecifications}

In the realm of electronic product development, PCB design plays a crucial role in ensuring the optimal 
functionality and performance of microcontroller-based systems. This section will highlight some of the key 
points covered in the microcontroller's hardware design guidelines \cite{ESP8266HGL}, along with best practices 
for PCB design. These guidelines provide valuable insights into the recommended approaches for designing the hardware 
layout, addressing critical aspects such as power supply, signal integrity, component placement, and grounding. 
By adhering to these guidelines and following established best practices, designers can achieve robust and reliable 
PCB designs that maximize the microcontroller's potential and minimize potential issues during manufacturing and 
operation.

\subsubsection{ESP8266EX Power Supply Design}\label{02SubSub:PowerSupplyDesign}

Prior to the power traces reaching the analog power-supply pins (Pin1, 3, 4, 28, 29), the inclusion of a 10 $\mu$F capacitor, working 
in conjunction with a 0.1 $\mu$F capacitor, becomes necessary. Additionally, an arrangement of a C circuit and an L circuit is advised 
for the power supplies of Pin3 and Pin4.The C-L-C circuit should be positioned as proximate as possible to the analog power-supply pin \cite{ESP8266HGL}. 
For more information about these components, refer to Figure \ref{02fig:analogAndDigitalSupplies1}.
It is crucial to acknowledge that the power supply pathway can be susceptible to damage as a consequence of abrupt current surges 
during the transmission of analog signals by ESP8266EX. Consequently, it is imperative to incorporate an additional 10$\mu$F capacitor, 
packaged in either 0603 or 0805 dimensions, to complement the existing 0.1$\mu$F capacitor \cite{ESP8266HGL}.

\subsubsection{Layers Design}\label{02SubSub:LayersDesign}

On \cite{ESP8266HGL} there are two suggested models regarding the number and dispositions of layers on a PCB
that uses ESP8266EX (and by extension, an 2.4GHz RF antenna). The model with four layers was chosen. Here are 
the specifications: 

\begin{itemize}
    \item The initial layer corresponds to the uppermost part and is designated as the TOP layer, utilized for 
    signal lines and component placement.
    \item The subsequent layer represents the GND layer, dedicated solely to establishing a comprehensive ground plane without 
    the inclusion of signal lines.
    \item The following layer constitutes the POWER layer, exclusively reserved for the positioning of power lines. In certain 
    unavoidable situations, it is admissible to incorporate some signal lines within this layer.
    \item Lastly, the final layer denotes the BOTTOM layer, exclusively allocated for signal line placement. It is discouraged 
    to mount components on this particular layer.
\end{itemize}

Also, the power tracks should have a minimum size of 15 mils. The value used was 20 mils.

\subsubsection{Reset Track Design}\label{02SubSub:ResetTrackDesign}

The EXT\_RSTB (Pin32) possesses an internal pullup resistor and operates on an active low mechanism. To mitigate the possibility
of external disturbances causing unwarranted resets, it is advised to maintain a concise PCB trace for EXT\_RSTB and 
incorporate an RC circuit at this pin \cite{ESP8266HGL} (see section \ref{02SubSub:RCDelayResetCircuitry}).

\subsubsection{XTAL - Crystal Oscillator Design}

To ensure proper functioning of the crystal oscillator, it is recommended to position it as close as possible to 
the XTAL pins, while considering the length of the traces. However, it is crucial to maintain an appropriate distance 
between the crystal and the chip to avoid any interference. The recommended distance from the MCU is 0.8 mm. 
This distance helps prevent any potential disruption caused by the crystal's  proximity to the chip. Additionally, it 
is important to note that there should be no vias present on the input and output traces. This means that the traces 
should not cross layers, ensuring a clean and uninterrupted signal path for the crystal oscillator. 
This design consideration helps maintain the integrity of the crystal oscillator's signals and enhances the overall 
performance of the circuit.

\subsubsection{RF Antenna}\label{03Sub:RFAntenna}

The RF impedance characteristic is 50$\Omega$, which indicates the desired impedance for optimal signal transmission. 
It is crucial to have a complete ground plane to ensure proper grounding and minimize interference. The RF trace should be kept as 
short as possible, and it is recommended to have dense ground via stitching surrounding it for isolation purposes. The width of RF 
lines should be minimized, and additional dense vias should be placed around them. A $\pi$-type matching circuitry (see the PCB
file .kicad\_pcb on the ``KiCad Projeto Tractian'' folder).
should be allocated 
on the RF trace and positioned in close proximity to the RF Pin2. It is important to avoid the use of vias for the RF trace. When routing 
the RF trace, a 135° angle is preferred, or circular arcs can be utilized for trace bends. Furthermore, the RF antenna should be placed at 
a distance from high-frequency transmitting devices, such as crystal oscillators, DDR, and specific high-frequency clocks (for example,
SPI Clocks). Additionally, it is essential to keep USB ports, USB-to-UART signal chips, and UART signal lines (including traces, vias, 
test points, headers, etc.) as far away from the antenna as possible. More specific iformations can be seen on \cite{ESP8266HGL}.
For the circuitry previous to the antenna, see the Figure \ref{02fig:RFAntennaCircuitry}. For the its PCB design, the
Texas SWRA117D 2.4GHz - Left \cite{TexasRFAntenna} was used. \\ 

For the  50$\Omega$ impedance on track design, the following values were used (Figure \ref{02fig:50ohmImpedanceDesignA}). The calculation was done using the 
\textbf{AppCad} \textit{software} \cite{AppCad}. Notice that the inputed values are in mils.

\begin{figure}[H]
    \centering
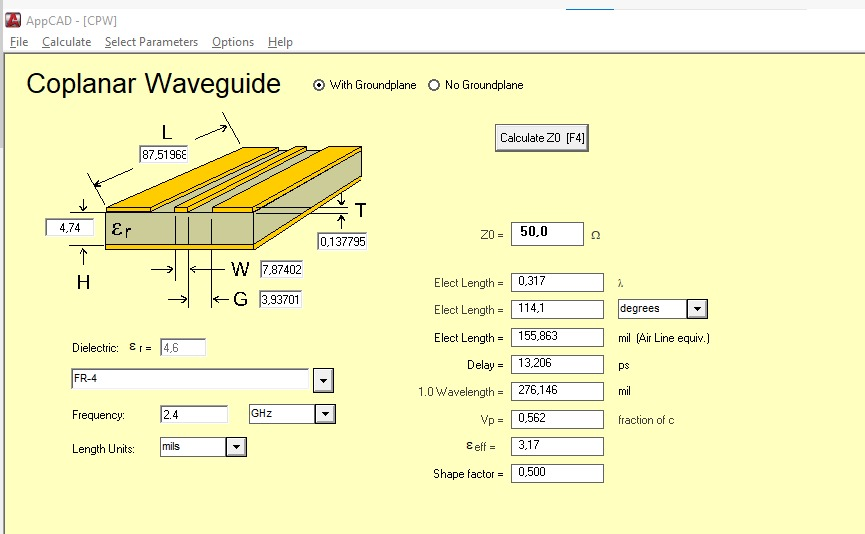
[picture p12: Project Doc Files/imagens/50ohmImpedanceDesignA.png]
    
    \caption{\textbf{Calculation of the 50$\Omega$ impedance - Coplanar Waveguide}.}
    \label{02fig:50ohmImpedanceDesignA}
\end{figure}

%%%%%%%%%%%     FIM      %%%%%%%%%%%  
%%%%%%%%        PCB         %%%%%%%%
%%%%%%%%%%%%%%%%%%%%%%%%%%%%%%%%%%%%

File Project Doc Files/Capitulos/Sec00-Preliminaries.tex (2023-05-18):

\newpage
%%%%%%%%%%%%%%%%%%%%%%%%%%%%%%%%%%%%
%%%%%%%%     Introduction   %%%%%%%%
%%%%%%%%%%%%%%%%%%%%%%%%%%%%%%%%%%%%

\section*{Preliminaries}\label{00Sec:Preliminaries}
\addcontentsline{toc}{section}{Preliminaries}

% \renewcommand{\thesubsection}{\MakeUppercase{\romannumeral\value{subsection}}}
\renewcommand{\thesubsection}{\roman{subsection}}
\subsection{Project overviewls}\label{01Sub:ProjectOverview}

The purpose of this project was to develop a firmware solution as part of a job interview for the 
position of Firmware Engineer at Tractian. The project involved designing and implementing hardware
and firmware for data transmissions through a wireless protocol. For this task, the WiFi protocol was
chosen. Although it wasn't necessary, it was added to the project the capability of data collection, so there was
actual information to be sent later. The device was equipped with a temperature sensor to capture data, which was then
stored in a flash EEPROM memory.

\subsection{Project objectives}\label{01Sub:ProjectObjectives}

The main objective of this project is to demonstrate the capabilities of a battery-powered device by successfully
transmitting a 500kB file across a challenging 100-meter open-air gap. This task requires efficient wireless communication
and optimized power management to ensure reliable and uninterrupted data transmission. By accomplishing this objective,
the project aims to showcase the device's ability to overcome distance limitations and deliver data wirelessly, even in challenging
environments.

%%%%%%%%%%%     FIM      %%%%%%%%%%%  
%%%%%%%%     Introduction   %%%%%%%%
%%%%%%%%%%%%%%%%%%%%%%%%%%%%%%%%%%%%
\renewcommand{\thesubsection}{\arabic{subsection}}

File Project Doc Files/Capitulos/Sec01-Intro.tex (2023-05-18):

\newpage
%%%%%%%%%%%%%%%%%%%%%%%%%%%%%%%%%%%%
%%%%%%%%     Introduction   %%%%%%%%
%%%%%%%%%%%%%%%%%%%%%%%%%%%%%%%%%%%%

\section{Introduction}\label{01Sec:Introduction}

This project aimed on the full development of a wireless communicating capable device,
from scratch all the way up to the final design. Throughout the development process, careful consideration
was given to hardware requirements and specifications. The firmware was optimized to ensure accurate temperature data
collection and efficient data transmission, while minimizing resource utilization and power consumption.
The firmware development encompassed various aspects, including the design of the firmware architecture,
algorithm implementation, and integration of communication protocols. \\ 

The following sections of this documentation provide detailed insights into the project's hardware and firmware
requirements, operation flow, device usage, limitations, and potential future improvements. The schematics and PCB layout
diagrams offer a comprehensive view of the hardware design, while the firmware section provides an in-depth analysis of the 
software implementation.

\subsection{Hardware Requirements}\label{01Sub:HardwareRequirements}

The chosen wireless protocol for this project was WiFi, and so, the ESP8266EX microcontroller was selected for its robustness, 
affordability, widespread acceptance in the firmware market and strong community support. Additionally, this MCU has the capability 
to work with RF signals at power levels of up to +20dBm in its TX, and sensitivities of -91dBm and -75dBm for 11Mbps and 54Mbps on 
its RX, respectively. Based on these values, under ideal conditions, signals can travel up to 300m. However, it is important to 
validate the project concept in real-world scenarios, where noisy environments and obstacles are almost always present. \\ 

For the temperature sensor, the TMP35 was chosen due to its low power consumption, ability to be powered off when not in use, 
good accuracy, and similarity to other widely used components in the market, such as the LM35. \\ 

As for the flash EEPROM memories, the MX25R3235F (32Mbit) and AT25SF081 (8Mbit) chips were selected for program and 
collected data storage, respectively. These ICs were chosen because they meet the size requirements (minimum 2MB for program and 
500kB for data) and operate under the serial SPI communication protocol.

\subsection{Firmware Requirements}\label{01Sub:FirmwareRequirements}

For the firmware, the development was chosen to be carried out using the Arduino IDE, as it works with C++,
a language accepted by the chosen microcontroller. Additionally, this IDE provides pre-developed board configurations,
which can be helpful during the prototyping phase. Moreover, it makes firmware uploading easier since we can utilize ready-made
modules for these tasks, such as the well-known ESP8266 NodeMCU 1.0.\\ 

For the WiFi protocol, the "ESP8266WiFi.h" library is used, licensed under the LGPL (Lesser General Public License) Version 2.1.
In broad terms, the license can be interpreted as follows: \\ 

\begin{flushright}
    \begin{quote}
        \textit{``Primarily used for software libraries, the GNU LGPL requires that derived works be licensed under the same 
        license,but works that only link to it do not fall under this restriction.''}
\end{quote}
\end{flushright}

The candidate chose to use this library because they do not have solid knowledge of the WiFi protocol (from the physical layer to 
the application layer) to develop their own library or subroutines. A full copy of the LGPL Ver 2.1 can be found at \cite{LGPL}. \\

For the communication between the microcontroller and the Flash Data Memory, the SPI communication protocol is used.
Also, the  it was implemented an algorithm for a linear time-invariant system, namely the Moving Average Filter. Such 
algorithm is required to ensure that the measured temperature remains in a stable state when it is saved in the flash data memory 
integrated into the hardware.

\subsection{Operation Flow}\label{01Sub:OperationFlow}

The final device workflow is simple: it stabilizes the reading/collecting of temperature data,
stores it on the flash EEPROM, and then opens communication with a access point, access a 
localhost webserver url and transmits the collected data. Finally, it erases the last $512,000$
samples of temperature and starts the process again.

\subsection{Limitations and Future Improvements}\label{01Sub:LimitationsAndFutureImprovements}

To reduce the code complexity, it was assumed that the server the board communicates with via the Access Point (AP) is a 
"localhost," and therefore, no SSL-HTTPS security configurations were implemented. Additionally, no ACK verification is performed 
to ensure that the server has indeed received the transmitted data. Furthermore, no HTTP POST messages containing SQL commands 
for writing to a hypothetical database are implemented. It is assumed that this set of business rules would be on the server side. 
Also, to avoid further increasing the code length (which has already been extended due to an unnecessary feature - reading 
temperature with precision and storing it in memory), no routines were implemented to ensure that the data was successfully written 
to the PCB memory. Finally, the device does not have any interface; it is simply plug and play. If there were any specific 
requirements, such an interface could be added subsequently.

%%%%%%%%%%%     FIM      %%%%%%%%%%%  
%%%%%%%%     Introduction   %%%%%%%%
%%%%%%%%%%%%%%%%%%%%%%%%%%%%%%%%%%%%

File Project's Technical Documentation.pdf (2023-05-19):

# Full Wireless Communication Device

Project documentation.

Caio Dutra

May 2023

## Contents

Preliminaries | 1
1 Introduction | 2
2 Circuitry | 4
3 Printed Circuit Board | 14
4 Firmware | 17

## Preliminaries

### i Project overviewls

The purpose of this project was to develop a firmware solution as part of a job interview for the position of Firmware Engineer at Tractian. The project involved designing and implementing hardware and firmware for data transmissions through a wireless protocol. For this task, the WiFi protocol was chosen. Although it wasn’t necessary, it was added to the project the capability of data collection, so there was actual information to be sent later. The device was equipped with a temperature sensor to capture data, which was then stored in a flash EEPROM memory.

### ii Project objectives

The main objective of this project is to demonstrate the capabilities of a battery-powered device by successfully transmitting a 500kB file across a challenging 100-meter open-air gap. This task requires efficient wireless communication and optimized power management to ensure reliable and uninterrupted data transmission. By accomplishing this objective, the project aims to showcase the device’s ability to overcome distance limitations and deliver data wirelessly, even in challenging environments.

## 1 Introduction

This project aimed on the full development of a wireless communicating capable device, from scratch all the way up to the final design. Throughout the development process, careful consideration was given to hardware requirements and specifications. The firmware was optimized to ensure accurate temperature data collection and efficient data transmission, while minimizing resource utilization and power consumption. The firmware development encompassed various aspects, including the design of the firmware architecture, algorithm implementation, and integration of communication protocols.

The following sections of this documentation provide detailed insights into the project’s hardware and firmware requirements, operation flow, device usage, limitations, and potential future improvements. The schematics and PCB layout diagrams offer a comprehensive view of the hardware design, while the firmware section provides an in-depth analysis of the software implementation.

### 1.1 Hardware Requirements

The chosen wireless protocol for this project was WiFi, and so, the ESP8266EX microcontroller was selected for its robustness, affordability, widespread acceptance in the firmware market and strong community support. Additionally, this MCU has the capability to work with RF signals at power levels of up to +20dBm in its TX, and sensitivities of -91dBm and -75dBm for 11Mbps and 54Mbps on its RX, respectively. Based on these values, under ideal conditions, signals can travel up to 300m. However, it is important to validate the project concept in real-world scenarios, where noisy environments and obstacles are almost always present.

For the temperature sensor, the TMP35 was chosen due to its low power consumption, ability to be powered off when not in use, good accuracy, and similarity to other widely used components in the market, such as the LM35.

As for the flash EEPROM memories, the MX25R3235F (32Mbit) and AT25SF081 (8Mbit) chips were selected for program and collected data storage, respectively. These ICs were chosen because they meet the size requirements (minimum 2MB for program and 500kB for data) and operate under the serial SPI communication protocol.

### 1.2 Firmware Requirements

For the firmware, the development was chosen to be carried out using the Arduino IDE, as it works with C++, a language accepted by the chosen microcontroller. Additionally, this IDE provides pre-developed board configurations, which can be helpful during the prototyping phase. Moreover, it makes firmware uploading easier since we can utilize ready-made modules for these tasks, such as the well-known ESP8266 NodeMCU 1.0.

For the WiFi protocol, the ”ESP8266WiFi.h” library is used, licensed under the LGPL (Lesser General Public License) Version 2.1. In broad terms, the license can be interpreted as follows:

“Primarily used for software libraries, the GNU LGPL requires that derived works be licensed under the same license,but works that only link to it do not fall under this restriction.”

The candidate chose to use this library because they do not have solid knowledge of the WiFi protocol (from the physical layer to the application layer) to develop their own library or subroutines. A full copy of the LGPL Ver 2.1 can be found at [9].

For the communication between the microcontroller and the Flash Data Memory, the SPI communication protocol is used. Also, the it was implemented an algorithm for a linear time-invariant system, namely the Moving Average Filter. Such algorithm is required to ensure that the measured temperature remains in a stable state when it is saved in the flash data memory integrated into the hardware.

### 1.3 Operation Flow

The final device workflow is simple: it stabilizes the reading/collecting of temperature data, stores it on the flash EEPROM, and then opens communication with a access point, access a localhost webserver url and transmits the collected data. Finally, it erases the last 512, 000 samples of temperature and starts the process again.

### 1.4 Limitations and Future Improvements

To reduce the code complexity, it was assumed that the server the board communicates with via the Access Point (AP) is a ”localhost,” and therefore, no SSL-HTTPS security configurations were implemented. Additionally, no ACK verification is performed to ensure that the server has indeed received the transmitted data. Furthermore, no HTTP POST messages containing SQL commands for writing to a hypothetical database are implemented. It is assumed that this set of business rules would be on the server side. Also, to avoid further increasing the code length (which has already been extended due to an unnecessary feature - reading temperature with precision and storing it in memory), no routines were implemented to ensure that the data was successfully written to the PCB memory. Finally, the device does not have any interface; it is simply plug and play. If there were any specific requirements, such an interface could be added subsequently.

## 2 Circuitry

### 2.1 Block Diagram

The block diagram of the device on the Figure 1 consists of several main components that play essential roles in its operation. Here is a brief overview of each of these parts:

Microcontroller (ESP8266EX): The ESP8266EX microcontroller is the central component of the device. It is responsible for controlling all operations and functionalities, including wireless communication via WiFi.

Program Memory (MX25R3235F): The program memory is where the device’s firmware is stored.

Data Memory (AT25SF081): The data memory is used to store the collected data in the device.

Temperature Sensor (TMP35): The TMP35 temperature sensor measures the ambient temperature.

RF Antenna (Texas SWRA117D 2.4GHz - Left): The RF antenna plays a crucial role in the wireless communication of the device. It enables the transmission and reception of radio signals, allowing WiFi communication. The RF antenna ensures a stable and reliable connection between the device and the access point (AP), facilitating the transmission of collected data. More information on this type of PCB antenna can be found at [3].


Figure 1: Device’s block diagram.

### 2.2 Schematics

To further delve into the circuit’s details, on Figure 2 is the schematic diagram of the circuit. It is also divided into four blocks, each serving a specific purpose in the device’s functionality as follows:

Power Supply Block: The power supply block provides a stable +3.3V voltage to the entire circuit. It ensures that all components receive the necessary power to operate efficiently and reliably. The power supply block includes a 3.7V (mAh to be decidade, depending on the longevity needed) and a voltage regulators. Decoupling capacitors and other necessary components to regulate and distribute power are cointained in the “Main Circuitry” (see Figure 2).

Program and Data Memory Block: This block encompasses the program and data memories of the device. The program memory, represented by the MX25R3235F chip, stores the firmware responsible for controlling the device’s operations. The data memory, represented by the AT25SF081 chip, stores collected data for future transmissions. This block includes the necessary connections between the microcontroller and the memory chips.

Temperature Sensing Block: The temperature sensing block includes the temperature sensor component (TMP35) and its associated circuitry. The sensor measures the ambient temperature and then converts it temperature reading into a eletctrical analog format for processing by the microcontroller. This block is responsible for accurate temperature measurement and data acquisition.

Main Block (Microcontroller and Components): The main block contains the microcontroller (ESP8266EX) and its associated components, in addition to the 2.4GHz RF antenna. The microcontroller serves as the central processing unit of the device, executing firmware instructions and coordinating various operations. This block includes components such as crystal oscillators, capacitors, resistors and inductors; these are the supporting elements necessary for the microcontroller’s functionality.

These four blocks work together to ensure the device’s proper operation. The power supply block provides the necessary voltage, the program, and data memory block stores and retrieves essential information, the temperature sensing block enables temperature measurement. Last but not least, the main block with the microcontroller controls and manages the device’s overall functionality.


Figure 2: Circuit Schematics.

6

### 2.3 Circuit Diagrams

We start highlitning the main points of the Main Circuitry, putting important design requirements for the properly function of the ESP8266EX. Most of the references were obtained on [5] and [4].

### 2.3.1 Digital and Analog Supplies Circuitry

For the analog power supply, ESP8266EX features five analog pins dedicated to power supply, encompassing Pin1, Pin3, and Pin4, which specifically cater to the power requirements of the internal PA and LNA. Furthermore, Pin29 and Pin30 serve as power inputs for the internal PLL. The acceptable voltage range for these analog power supply pins spans from 2.5 V to 3.6 V [4].

As for the digital power suplly, ESP8266EX is equipped with two digital pins, namely Pin11 and Pin17, dedicated to power supply. When it comes to the digital power supply, the inclusion of supplementary filter capacitors is unnecessary. The operational voltage range for the digital power supply pins spans from 1.8 V to 3.3 V [4] Both Analog and Digital power supply connections can be seen on Figure 3

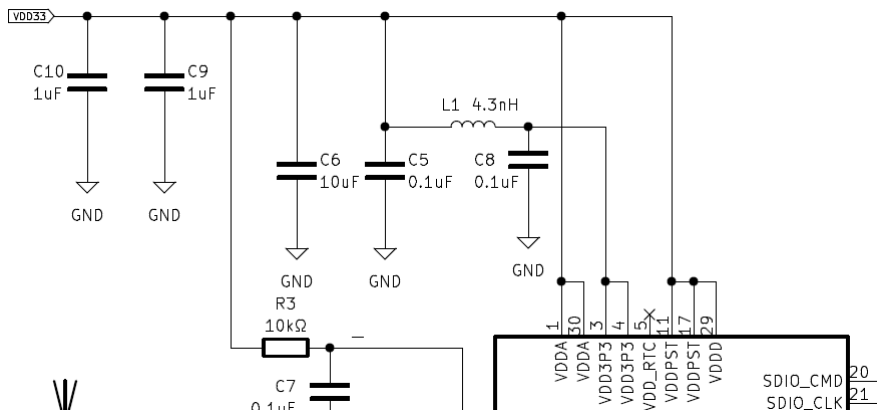
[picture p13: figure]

Figure 3: Digital and Analog Supplies Circuitry.

### 2.3.2 RC Delay Reset Circuitry

The reset pin of ESP8266EX is denoted as Pin32 EXT RSTB and plays a vital role in the device’s operation [4]. This pin possesses an internal pullup resistor and operates on an active low mechanism. As for Pin7 CHIP EN, it functions as the enable pin for ESP8266EX. When held at a low state, ESP8266EX powers off [4]. Its connections can see on the Figure 2.3.2 shwon in the section (2.3.3) below.

2.3.3 12Kohm RES

An external GND 12kΩ showed on Figure 2.3.2 resistor should be connected with the ERS12K pin (pin 31) [4]. This component must have high accuracy when controlling the bias current. For this, a 12kΩ ± 1% is required.

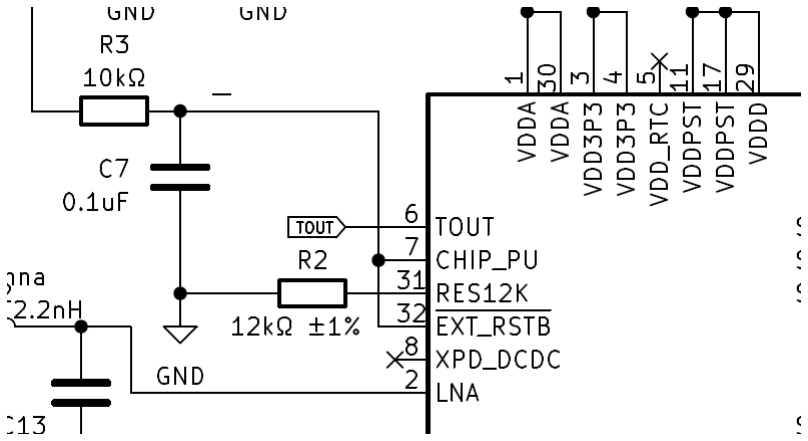
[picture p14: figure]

Figure 4: RC Delay Reset circuitry and 12K RES Pin.

### 2.3.4 RF Antenna Circuitry

For the 2.4Ghz RF antenna, in terms of “abstract” circuit itself, the only requirements is that the the impedance at the output terminal of the ESP8266 power amplifier is 39 + j6Ω, which necessitates a corresponding matched impedance of 39 − j6Ω (from the antenna to the chip). Moreover, for the RF PCB design, a 50Ω impedance is required on the track design. For such implementation, see the Figure 5 below (also, see the section 3.2.5).

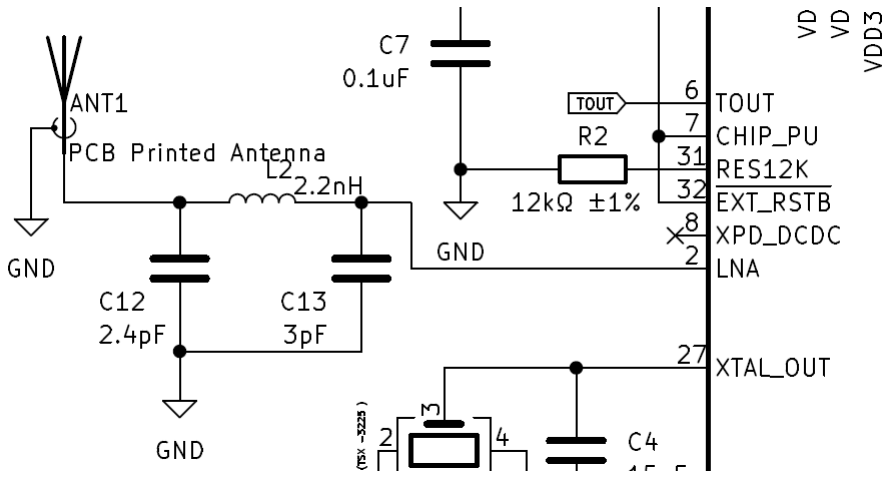
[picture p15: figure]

Figure 5: 2.4GHz Antenna circuitry.

### 2.3.5 XTAL Circuitry

ESP8266EX has the capability to support crystal oscillators with frequencies of 40 MHz, 26 MHz, and 24 MHz. In the circuit design, capacitors C4 and C11 are connected to the ground and added to the input and output terminals of the crystal oscillator, respectively. The values of these capacitors can be varied within a range of 6 pF to 22 pF - 15pF was chosen. It is crucial that the crystal oscillator used has a precision of ±10 PPM (parts per million) to maintain accurate timing and synchronization. For the XTAL chip, the FA238 (26Mhz) From Seiko Epson Corporation was chosen [6]. The electrical connection for the crystal oscillator is shown in Figure 6.


Figure 6: Crystal Oscillator Circuitry.

### 2.3.6 Drive Current Serial Clock RES

To reduce drive current and eliminates external interruptions, a 200 Ω is connected to the flashs (Pin21 SD CLK and Pin9 MTMS). It is recommended a 0402 resistor package [4].


Figure 7: 200Ω RES Drive Current.

As for the Nets connected on each of the pins shown in Figure 7, “P” stands for “Program”, “D” is “Data”, “SI” and “SO” are “Serial IN” (MOSI) and “Serial Out” (MISO) respectivily (notice the “IN” “Out” refers to the slave pins). Moreover, “SCLK” means “Serial Clock”, “WP” is “Write Protect’, “HD” refers to “Hold”. Finnaly, “TEMPSD” stands for “TMP 35 Shutdown”. So, for instance, “DMCLK” refers to the “Data Memory Serial Clock” Net. From this point, the rest of the blocks are described.

### 2.3.7 Power Circuitry

For the power circuitry, a 3.7V battery is used, along with a voltage regulator. The AMS1117
[2] for 3.3V integrated circuit (IC) was utilized to ensure protection and integrity of the power supply.


Figure 8: 3.3V Power circuitry.

### 2.3.8 Storage Circuitry

As for the program memory, since there is no internal memory available, an external flash memory is required for the ESP8266EX to store the user program. It is important to consider that the minimum capacity of the memory should be 512kB for disabled OTA (firmware updates Over The Air) or 1MB for enabled OTA. For firmware programming into the memory, the ESP8266EX supports Standard SPI, Dual SPI, and Quad SPI, which need to be selected prior to the programming process. The chosen memory, MX25R3235F [10], meets all the aforementioned requirements.

For the data memory, the requirements essentially boil down to having sufficient space (min 500kB) and supporting SPI communication. The chosen IC, AT25SF081 [1], fulfills these requirements. Additionally, this IC allows for serial data traffic on its I/Os at speeds of up to 50MHz (85MHz and 104MHz in specific cases). Since the communication with this chip was achieved through bit banging (see section 4.4 ), with an SCLK oscillation period of 6µs, i.e., a frequency of f = 166.666kHz, operating with this chip is entirely feasible, obviating the need for hardware-based SPI interface. Furthermore, The protection bits are set to zero by default [1], and there is no need to modify these bits. Therefore, the memory can be programmed and erased without any difficulties. Both program and data memory can be seen on Figure 9


Figure 9: Storage circuitry - Program and Data Memory.

### 2.3.9 Temperature Sensor Circuitry

The TMP35 temperature sensor [7] provides analog temperature readings, which can be converted into temperature values using appropriate calibration by “voltage divider circuit” shown in the Figure 10. This adjustment is need as the ESP8266EX ADC Input can only receive values between 0 and 1V [5].


Figure 10: Temperature measuring circuitry.

## 3 Printed Circuit Board

### 3.1 PCB Design

### 3.2 PCB Specifications

In the realm of electronic product development, PCB design plays a crucial role in ensuring the optimal functionality and performance of microcontroller-based systems. This section will highlight some of the key points covered in the microcontroller’s hardware design guidelines [4], along with best practices for PCB design. These guidelines provide valuable insights into the recommended approaches for designing the hardware layout, addressing critical aspects such as power supply, signal integrity, component placement, and grounding. By adhering to these guidelines and following established best practices, designers can achieve robust and reliable PCB designs that maximize the microcontroller’s potential and minimize potential issues during manufacturing and operation.

### 3.2.1 ESP8266EX Power Supply Design

Prior to the power traces reaching the analog power-supply pins (Pin1, 3, 4, 28, 29), the inclusion of a 10 µF capacitor, working in conjunction with a 0.1 µF capacitor, becomes necessary. Additionally, an arrangement of a C circuit and an L circuit is advised for the power supplies of Pin3 and Pin4.The C-L-C circuit should be positioned as proximate as possible to the analog power-supply pin [4]. For more information about these components, refer to Figure 3. It is crucial to acknowledge that the power supply pathway can be susceptible to damage as a consequence of abrupt current surges during the transmission of analog signals by ESP8266EX. Consequently, it is imperative to incorporate an additional 10µF capacitor, packaged in either 0603 or 0805 dimensions, to complement the existing 0.1µF capacitor [4].

### 3.2.2 Layers Design

On [4] there are two suggested models regarding the number and dispositions of layers on a PCB that uses ESP8266EX (and by extension, an 2.4GHz RF antenna). The model with four layers was chosen. Here are the specifications:

The initial layer corresponds to the uppermost part and is designated as the TOP layer, utilized for signal lines and component placement.

The subsequent layer represents the GND layer, dedicated solely to establishing a comprehensive ground plane without the inclusion of signal lines.

The following layer constitutes the POWER layer, exclusively reserved for the positioning of power lines. In certain unavoidable situations, it is admissible to incorporate some signal lines within this layer.

Lastly, the final layer denotes the BOTTOM layer, exclusively allocated for signal line placement. It is discouraged to mount components on this particular layer.

Also, the power tracks should have a minimum size of 15 mils. The value used was 20 mils.

### 3.2.3 Reset Track Design

The EXT RSTB (Pin32) possesses an internal pullup resistor and operates on an active low mechanism. To mitigate the possibility of external disturbances causing unwarranted resets, it is advised to maintain a concise PCB trace for EXT RSTB and incorporate an RC circuit at this pin [4] (see section 2.3.2).

### 3.2.4 XTAL - Crystal Oscillator Design

To ensure proper functioning of the crystal oscillator, it is recommended to position it as close as possible to the XTAL pins, while considering the length of the traces. However, it is crucial to maintain an appropriate distance between the crystal and the chip to avoid any interference. The recommended distance from the MCU is 0.8 mm. This distance helps prevent any potential disruption caused by the crystal’s proximity to the chip. Additionally, it is important to note that there should be no vias present on the input and output traces. This means that the traces should not cross layers, ensuring a clean and uninterrupted signal path for the crystal oscillator. This design consideration helps maintain the integrity of the crystal oscillator’s signals and enhances the overall performance of the circuit.

### 3.2.5 RF Antenna

The RF impedance characteristic is 50Ω, which indicates the desired impedance for optimal signal transmission. It is crucial to have a complete ground plane to ensure proper grounding and minimize interference. The RF trace should be kept as short as possible, and it is recommended to have dense ground via stitching surrounding it for isolation purposes. The width of RF lines should be minimized, and additional dense vias should be placed around them. A πtype matching circuitry (see the PCB file .kicad pcb on the “KiCad Projeto Tractian” folder). should be allocated on the RF trace and positioned in close proximity to the RF Pin2. It is important to avoid the use of vias for the RF trace. When routing the RF trace, a 135° angle is preferred, or circular arcs can be utilized for trace bends. Furthermore, the RF antenna should be placed at a distance from high-frequency transmitting devices, such as crystal oscillators, DDR, and specific high-frequency clocks (for example, SPI Clocks). Additionally, it is essential to keep USB ports, USB-to-UART signal chips, and UART signal lines (including traces, vias, test points, headers, etc.) as far away from the antenna as possible. More specific iformations can be seen on [4]. For the circuitry previous to the antenna, see the Figure 5. For the its PCB design, the Texas SWRA117D 2.4GHz - Left [3] was used.

For the 50Ω impedance on track design, the following values were used (Figure 11). The calculation was done using the AppCad software [8]. Notice that the inputed values are in mils.


Figure 11: Calculation of the 50Ω impedance - Coplanar Waveguide.

## 4 Firmware

### 4.1 Firmware Description

The ultimate goal of this firmware is to establish a complete wireless communication between a data collecting station (ESP8266EX) and an access point located 100m away using the WiFi protocol. The hardware collects data on-site, stores it with a size of 500kB, and then sends it to the access point.

For the purpose of data collection, a temperature measuring circuit was implemented on the hardware using a TMP36 IC. A linear time-invariant system, namely the Moving Average Filter, is required to ensure that the measured temperature remains in a stable state when it is saved in the flash data memory integrated into the hardware.

For the WiFi protocol, the library ”ESP8266WiFi.h” was used.

For the communication between the microcontroller and the Flash Data Memory, it is used the SPI communication protocol.

### 4.2 Configurations and Parameters

The code includes various configurations and parameters for an ESP8266 program involving SPI communication, temperature reading, and Wi-Fi transmission. These parameters are the following.

The <ESP8266WiFi.h> library is a header file specific to the ESP8266 platform. It provides the necessary functions and definitions to enable Wi-Fi connectivity and communication on the ESP8266 module. This library allows the program to connect to Wi-Fi networks, perform network-related operations, and establish connections with hosts over the network. WiFiClient hostClient instance:

The WiFiClient hostClient; creates an instance of the WiFiClient class named hostClient. The WiFiClient class is part of the ESP8266WiFi library and represents a client connection in a Wi-Fi network. In this case, hostClient is used to establish a connection with the host specified in the code (HOST). It will be responsible for handling the communication between the ESP8266 and the host, enabling data transmission over the established connection.

By creating an instance of WiFiClient, the program can make use of its methods and functionalities to connect to a host and exchange data.
GPIOs for SPI communication with data memory:

DMCS: Data Memory Chip/Slave Select, set to 15 (GPIO15).

DMCLK: Data Memory Serial Clock, set to 14 (GPIO14).

DMSI: Data Memory SI (slave data input) (MOSI), set to 13 (GPIO13).

DMSO: Data Memory SO (slave data output) (MISO), set to 12 (GPIO12).

DMWP: Data Memory Write Protect, set to 0 (GPIO0).

DMHD: Data Memory Hold, set to 2 (GPIO2).

SPI delay for 8 MHz communication:

Half SPI Period: delay period for SPI communication in microseconds, set to 3. This corresponds to a frequency of approximately 166.666 kHz.

Temperature sensor GPIO definitions:

Temp Sensor ADC Pin: analog input pin (ADC) for TMP35 sensor output, set to 17.

Temp Sensor Shutdown Pin: shutdown pin (SHUTDOWN) for TMP35 sensor, set to 5 (GPIO5).

Network settings:

SSID: Service Set Identifier (SSID) of the Wi-Fi network to be connected, set to ”Fake WiFi Net To Connect”.

PSSWRD: Password of the Wi-Fi network to be connected, set to ”Fake WiFi Net Password”.

HOST: Fake URL to send data, set to ”192.13.14.5/temperature log files”. It is assumed
to be used for sending a 500 kB file.

httpPort: HTTP port to be used, set to 80.

Arrays and variables related to temperature data reading and sending:

Temp Vector: byte array that stores 256 samples of stable temperature measurements.

Temp Buffer: buffer to store 50 samples of instantaneous temperature readings.

| addressBytes: byte array with 3 bytes for memory address.
| readData: byte array used to read 1 kB of information from data memory and send it to the host.

ADDRESS: starting memory address for writing, set to 0x000000.

| packetCount: counter for packets sent to the host.
| numOfTries: counter for the number of connection attempts to the host before giving up and collecting another set of temperature values.

p: counter for the 500 kB file (counts the number of 1024-byte packets sent to the host).

q: counter for the 1024 bytes to be sent in readData.

The actual code for this configurations are shown bellow:

1
2 #include <ESP8266WiFi.h>
3
4 WiFiClient _hostClient; // creates an instance of WifiClient for the host to be connected
5
6 // Data Memory GPIO’s definitions for SPI comm:
7 #define DMCS 15 // Data Memory Chip/Slave Select - Pin 13 on ESP8266EX -> (MTDO) GPIO15
8 #define DMCLK 14 // Data Memory Serial Clock - Pin 9 on ESP8266EX -> (MTMS) GPIO14
9 #define DMSI 13 // Data Memory SI (slave data input) (MOSI) - Pin 12 on ESP8266EX -> (MTCK) GPIO13
10 #define DMSO 12 // Data Memory SO (slave data output) (MISO) - Pin 10 on ESP8266EX -> (MTDI) GPIO12
11 #define DMWP 0 // Data Memory Write Protect - Pin 15 on ESP8266EX -> (GPIO0) GPIO0
12 #define DMHD 2 // Data Memory Hold - Pin 14 on ESP8266EX -> (GPIO2) GPIO2
13
14 // SPI delay for 8Mhz comm (Flash Data Memory operates up to 8Mhz for single IO mode)
15 // For we are using bit banging data, a (way) lower frequency will be used.
16 // Acording to Arduino Reference, for ’delayMicroseconds(t);’ operates very accurately
17 // for a minimum valeu of t = 3 (3us). Being so, The period of the SCLK shall be 6us,
18 // which leads to f = 166.666 kHz. That being said, every 3 seconds or so 500,000
19 // samples of temperature will be collected. This barely has any practical uses,
20 // but the principle of the challenge stands.
21 #define Half_SPI_Period 3 // for f = 8MHz , T = 6us
22
23 // Temperature Sensor GPIO definition
24 #define Temp_Sensor_ADC_Pin 17 // TMP35 Vout - Pin 6 on ESP8266EX
-> (TOUT) ADC_in | On NodeMCU it is mapped to pin 17
25 #define Temp_Sensor_Shutdown_Pin 5 // TMP35 SHUTDOWN - Pin 24 on ESP8266EX -> (GPIO5) GPIO5
26

27 const char* SSID = "Fake_WiFi_Net_To_Connect"; // service set identifier of the AP to be connected
28
29 const char* PSSWRD = "Fake_WiFi_Net_Password"; // net password of the AP to be connected
30
31 const char* HOST = "192.13.14.5/temperature_log_files"; // Fake URL to send data (500kB file)
32
33 const int _httpPort = 80; // HTTP Port to be used
34
35 // Global Array to store 256 Stable Temperature Readings (later to be used on Data Memory Write)
36 byte Temp_Vector[256]; // records 256 sample of stables temp measurements to record on a page on Data Memory
37 byte Temp_Buffer[50]; // Buffer to stores 50 samples of intantaneous Temperature readings
38
39 // 3Byte Memory Address
40 byte _addressBytes[3];
41
42 // 1024 array for reading from data memory and sending via WiFi ( total of 500 packets of 1024 bytes to be sent -> 500kB)
43 byte _readData[1024];
44
45 // Memory Address Word
46 unsigned long ADDRESS = 0x000000; // By our definition, Memory Write starts at address 0
47 int _packetCount = 0; // count var for Page Program
48
49
50 int _numOfTries = 0; // starts with 0 - count the number of times the station tried to connect with to host before it gives up and leads to another set of collecting tempereture values
51 // int _connectionSuccess; // indicates if the connection to the host was sucessful (1) or not (0)
52
53
54 int p; // count var for 500kB file (counts the number os 1024bytes packets sent to the host - total of 512,000 bytes)
55 int q; //count var (parameter of _readData) for 1024 bytes to be sent

### 4.3 Firmware Architecture

At a high level, the code operates with the following flowchart to outline its functionality. First, it performs a setup process to initialize necessary variables and configurations. Then, it enters the main loop where it activates the temperature sensor, collects temperature data, and stores it in memory. Afterward, it turns off the temperature sensor. Next, it attempts to establish a connection with the designated Wi-Fi Access Point (AP). If successful, it tries to connect to the host URL, allowing for a maximum of 10 connection attempts. If the connection is established, it sends the collected temperature data to the host. Finally, regardless of the connection utcome, the code disconnects from the host and returns to the beginning of the main loop to repeat the process. This flowchart provides a high-level overview of the code’s functionality and the sequential steps it follows to achieve its intended purpose.


Figure 12: High level overview of the firmware.

### 4.4 Features and Algorithms

In order to stabilize the instantaneous temperature readings, an Moving Average Filter Algorithm was implemented in the project. This algorithm takes a series of temperature measurements and calculates their average over a specified window of time or number of samples. By smoothing out variations and fluctuations in the temperature data, the Moving Average Filter Algorithm helps to provide a more stable and reliable temperature reading.

Additionally, as part of a possible future implementation, a general 3-byte array generator algorithm was implemented. This algorithm takes a long variable in the form of six nibbles ”0xXYZWTR” as input. It then extracts and organizes the individual nibbles of the long variable into a 3-byte array. This allows for efficient storage and manipulation of the long variable in byte-based operations. The 3-byte array representation offers flexibility for future use, such as data transmission, storage, or further processing, depending on the project’s requirements.

In addition to the mentioned components, the project also incorporates subroutines for Data Memory operations, including Write, Read, and Erase functionalities. These subroutines enable the program to interact with the Data Memory module connected to the ESP8266. The Write subroutine facilitates the storage of data, such as temperature readings or other relevant information, into the Data Memory. The Read subroutine allows retrieving data from the Data Memory, enabling access to previously stored information. Lastly, the Erase subroutine provides a mechanism to clear or reset the Data Memory, erasing any existing data stored within it. By implementing these subroutines, the project gains the capability to effectively manage and manipulate data in the Data Memory module, facilitating data logging, analysis, or further processing as required.

### 4.5 Interfaces and Protocols

In the project, a routine for SPI communication using bit banging was implemented. This approach allows direct control over the individual signal lines involved in the SPI protocol. The SPI protocol is widely used for communication between microcontrollers and peripheral devices such as the data memory chip in this case. The implemented routine operates on Mode 0, which is accepted by the data memory chip. Mode 0 means that the clock signal is idle low, and data is sampled on the leading edge of the clock signal.

The SPI communication routine has a clock period of 6 microseconds (6µs), resulting in a frequency of approximately 166,666 kHz. This frequency falls within the acceptable range supported by the memory IC, ensuring reliable and efficient data transfer. By utilizing bit banging and adhering to the Mode 0 protocol with an appropriate clock frequency, the implemented routine enables effective communication between the ESP8266 and the data memory chip, facilitating data read/write operations and supporting the overall functionality of the project.

## References

[1] 8-Mbit SPI Serial Flash Memory with Dual-I/O and Quad-IO Support - AT25SF081
Datasheet. url: https://pdf1.alldatasheet.com/datasheet-pdf/view/606550/ETC2/AT25SF081.html. (https://pdf1.alldatasheet.com/datasheet-pdf/view/606550/ETC2/AT25SF081.html)
[2] Advanced Monolithic Systems - AMS1117 Datasheet. url: http://www.advanced-
monolithic.com/pdf/ds1117.pdf. (http://www.advanced-monolithic.com/pdf/ds1117.pdf)
[3] Application Note AN043 Small Size 2.4 GHz PCB antenna. url: https://www.ti.
com / lit / an / swra117d / swra117d . pdf ? ts = 1684435789781 & ref _ url = https%253A%252F%252Fwww.google.com%252F. (https://www.ti.com/lit/an/swra117d/swra117d.pdf?ts=1684435789781)
[4] ESP8266 Hardware Design Guidelines. url: https://www.espressif.com/sites/
default/files/documentation/esp8266_hardware_design_guidelines_ en.pdf. (https://www.espressif.com/sites/default/files/documentation/esp8266_hardware_design_guidelines_en.pdf)
[5] ESP8266EX Datasheet. url: https://www.espressif.com/sites/default/files/documentation/0a-esp8266ex_datasheet_en.pdf. (https://www.espressif.com/sites/default/files/documentation/0a-esp8266ex_datasheet_en.pdf)
[6] FA-238 Mhz Range Crystal Unit - FA238 Datasheet. url: https://br.mouser.com/
datasheet/2/137/FA_238_en-932914.pdf. (https://br.mouser.com/datasheet/2/137/FA_238_en-932914.pdf)
[7] Low Voltage Temperature Sensors TMP35/TMP36/TMP37 - TMP35 Datasheet. url:
http://www.advanced-monolithic.com/pdf/ds1117.pdf.
[8] The AppCad Software. url: https : / / www . broadcom . com / info / wireless / appcad. (https://www.broadcom.com/info/wireless/appcad)
[9] The GNU GLPL full text. url: https://github.com/esp8266/Arduino/blob/master/LICENSE. (https://github.com/esp8266/Arduino/blob/master/LICENSE)
[10] Ultra low power, 32Mbit [x 1/ x2/ x4] CMOS MXSMIO (Serial Multi I/O Flash Mem-
ory - MX25R3235F Datasheet). url: https : / / www . macronix . com / Lists / Datasheet/Attachments/8755/MX25R3235F,%20Wide%20Range,%2032Mb, %20v1.8.pdf. (https://www.macronix.com/Lists/Datasheet/Attachments/8755/MX25R3235F,%20Wide%20Range,%2032Mb,%20v1.8.pdf)

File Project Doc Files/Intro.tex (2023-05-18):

\section*{Introdução}

Este documento foi desenvolvido com o intuito de documentar todo o processo de contrução do sistema
Devlean. Além disso, tem por objetivo apontar funcionalidades e eventuais falhas pertinentes às
telas. Este documento específico diz respeito ao \textbf{MÓDULO DE VENDAS}. Todo o versionamento
da documentação será feito via ferramenta \textit{Git}, pelo \textit{GitHub}.\\

A construção a qual este documento se baseia é a classe ``Livro''. Assim, veremos que sua 
estutura é básica, sendo: Capa de apresentação, Introdução, Explicação do modelo, Sumário e Capítulos. 
Veja mais detalhes sobre essas divisões na seção seguinte (Explicação do modelo).\\

Por fim, a documentação também tem por objetivo apontar para a equipe de desenvolvimento falhas no sistema 
e/ou no código. Se forem encontrados problemas no sistema, mudanças e melhorias serão necessárias. Estas
estarão indicadas no documento intitulado ``\textbf{REQUERIMENTO DE MUDANÇAS E MELHORIAS}''. Caso for necessário
mudar o código sem alterar a aplicação, seja para aprimorar a lógica, deixa-lo menos verboso ou qualquer
coisa do tipo, as alterações necessárias estarão presentes no documento intitulado ``\textbf{REQUERIMENTO
DE REFATORAÇÃO}''. Mais detalhes também estarão presentes na seção a seguir. Os padrões destes documentos
estão nas Figuras \ref{fig:modeloRequerimentoMudanca}, \ref{fig:checkedBoxModeloRequerimento} e
\ref{fig:modeloRequerimentoRefatorecao}.

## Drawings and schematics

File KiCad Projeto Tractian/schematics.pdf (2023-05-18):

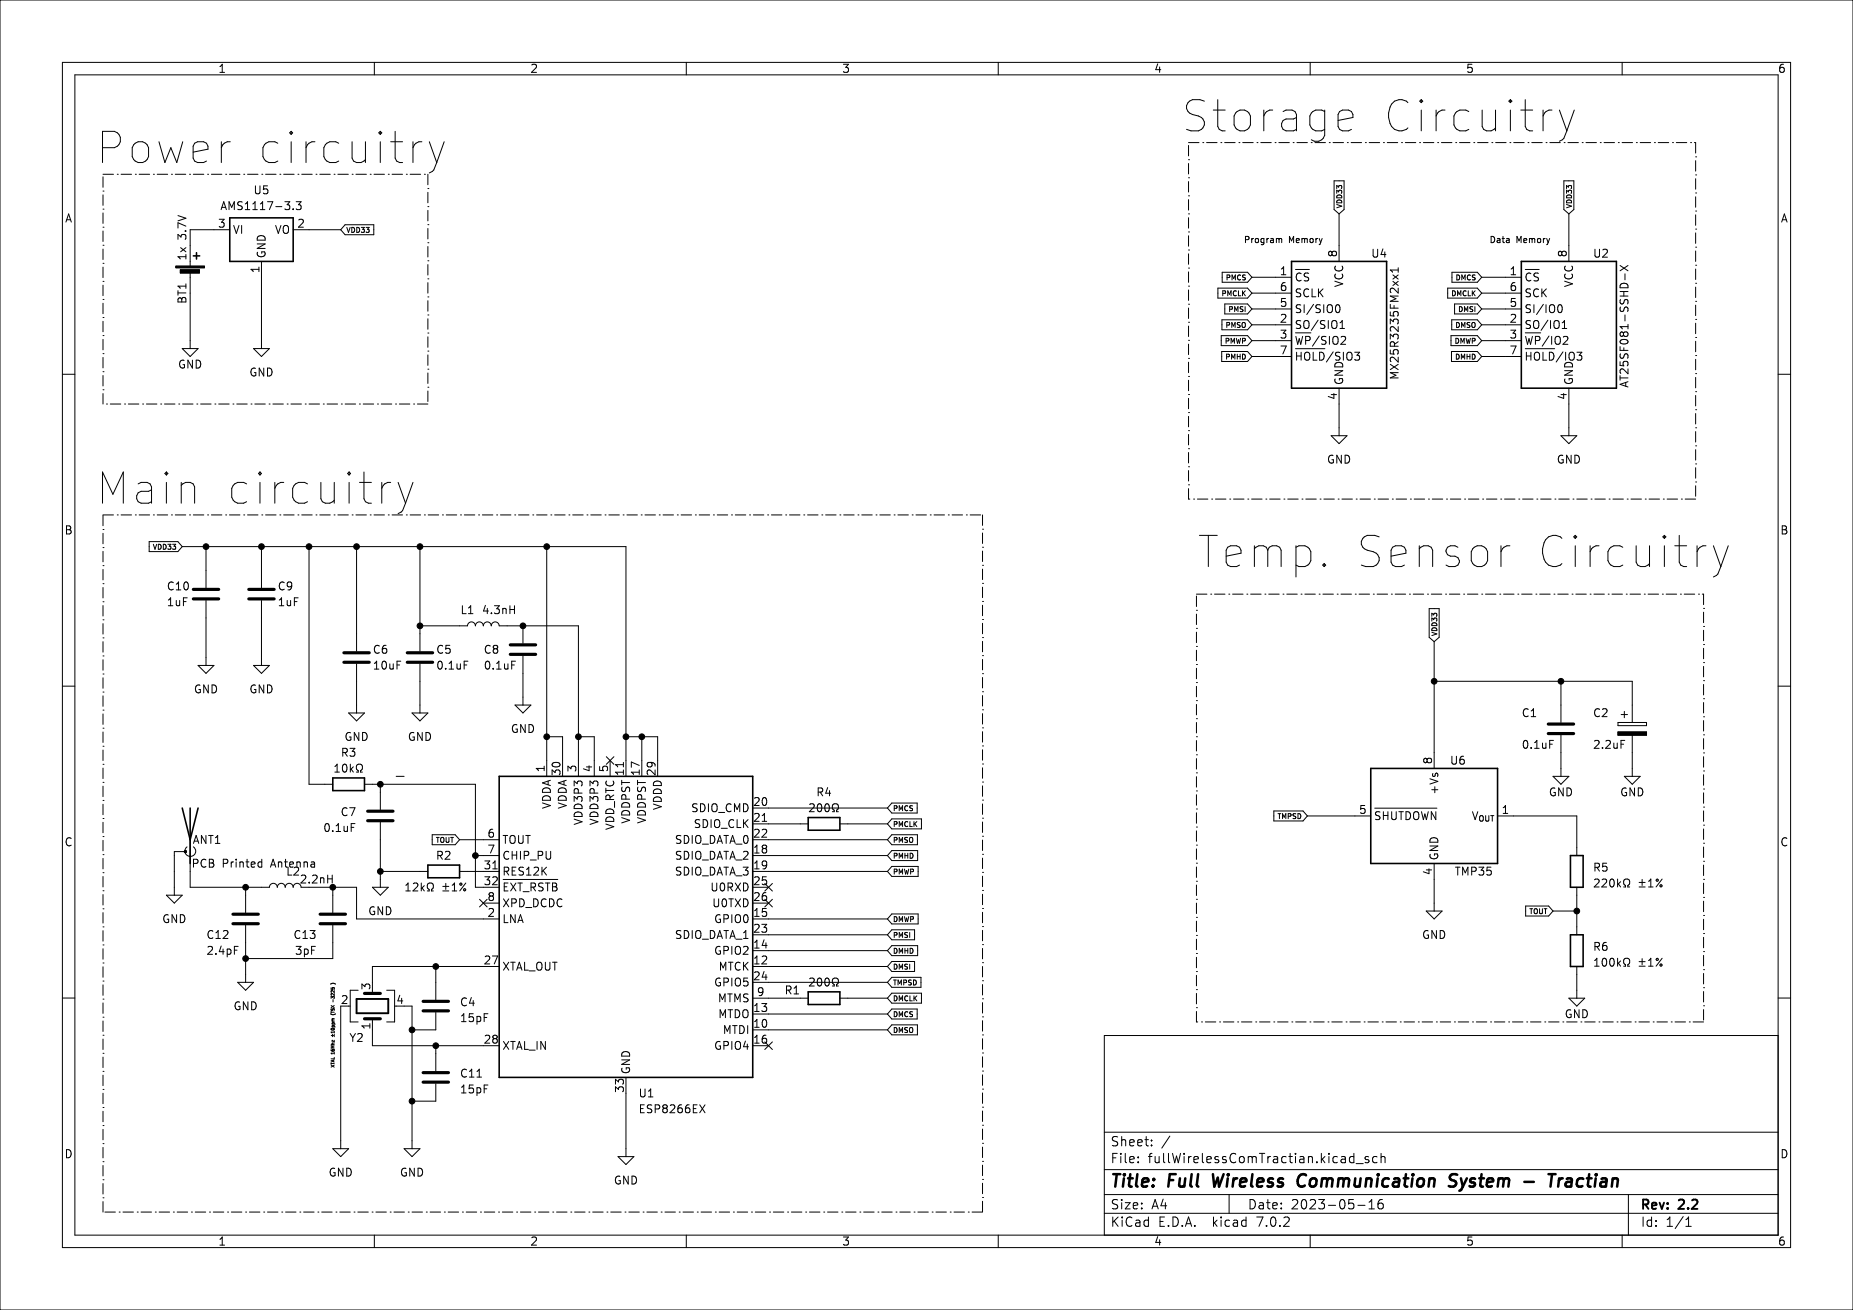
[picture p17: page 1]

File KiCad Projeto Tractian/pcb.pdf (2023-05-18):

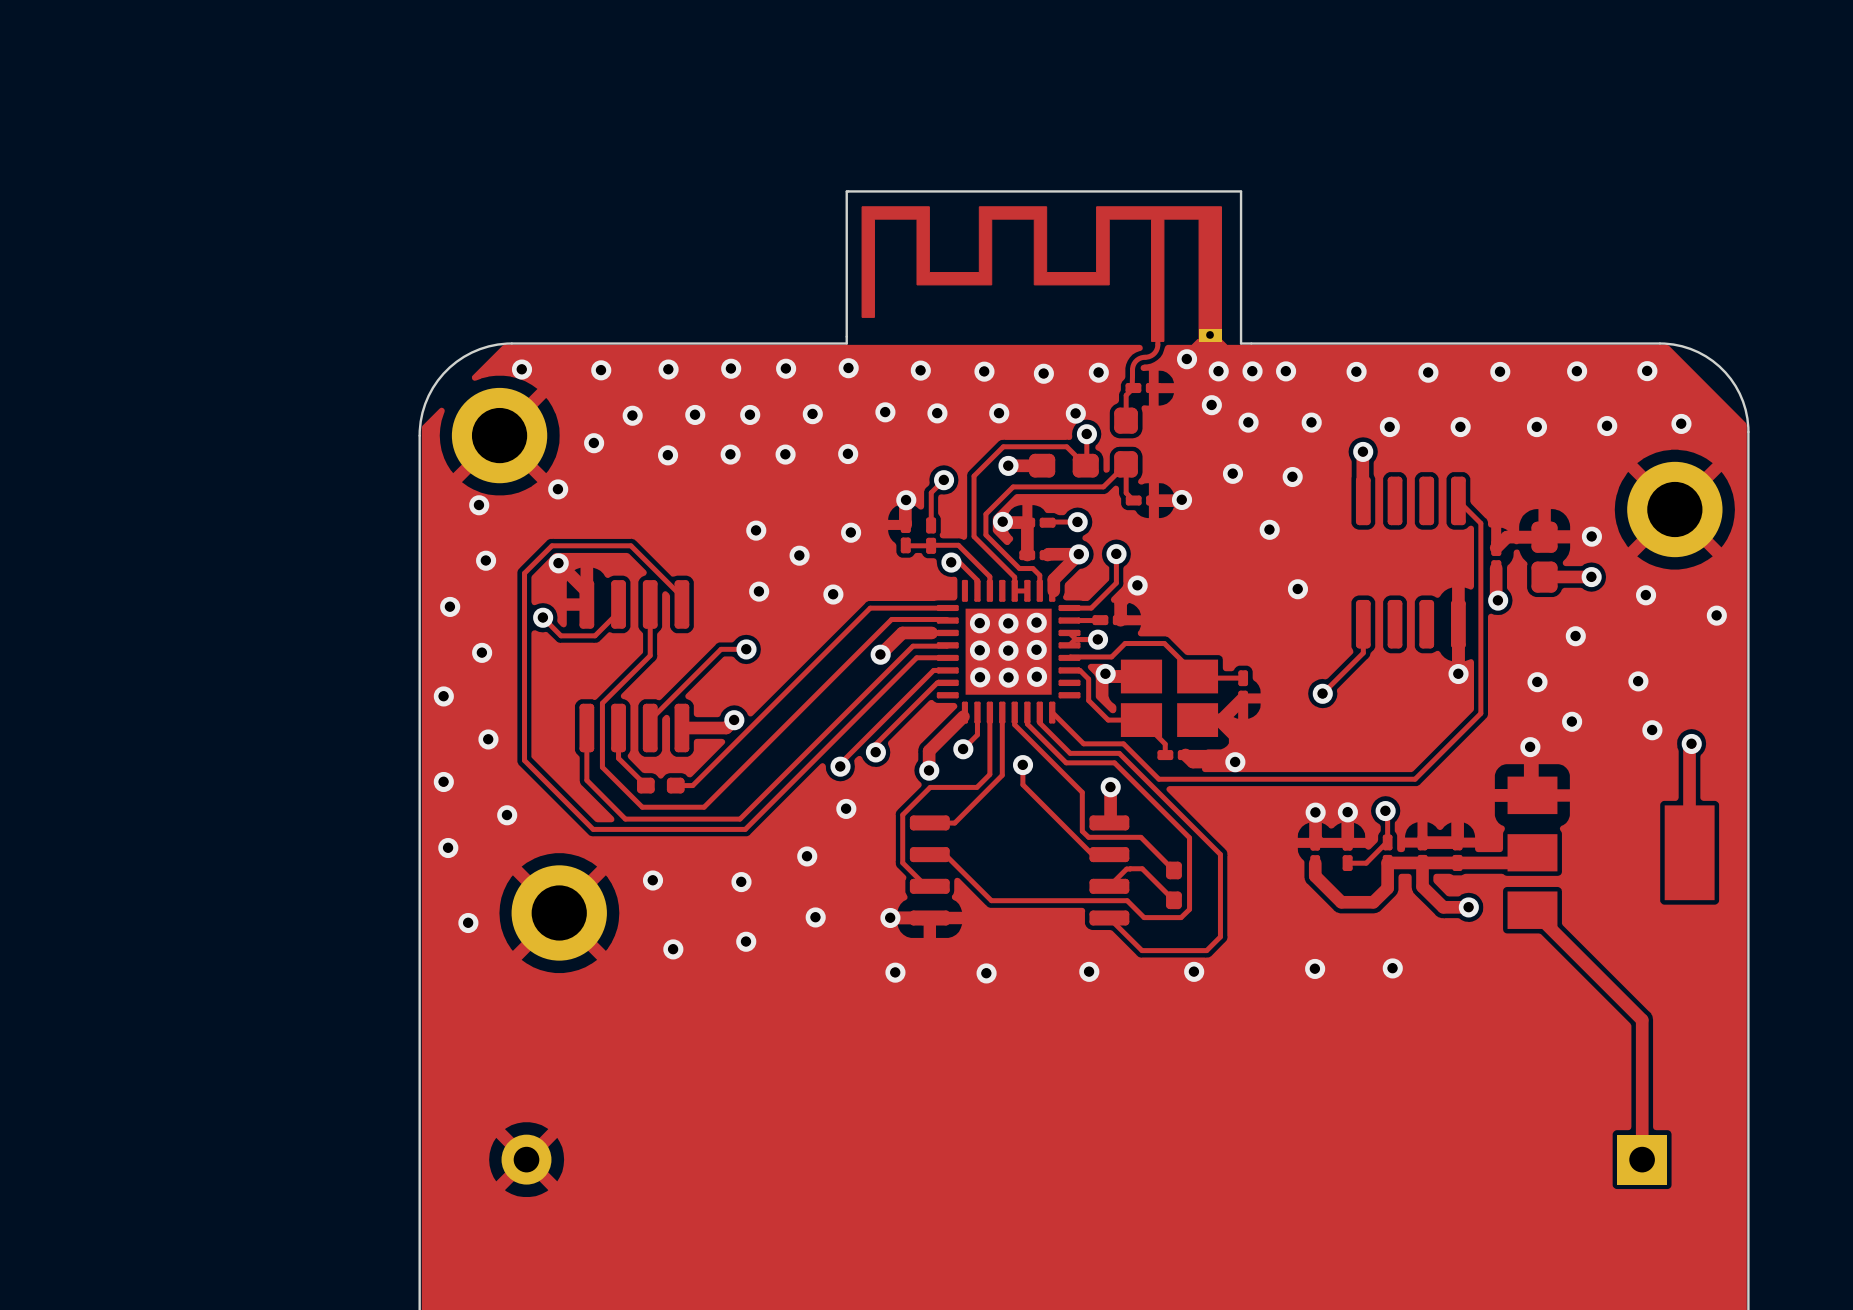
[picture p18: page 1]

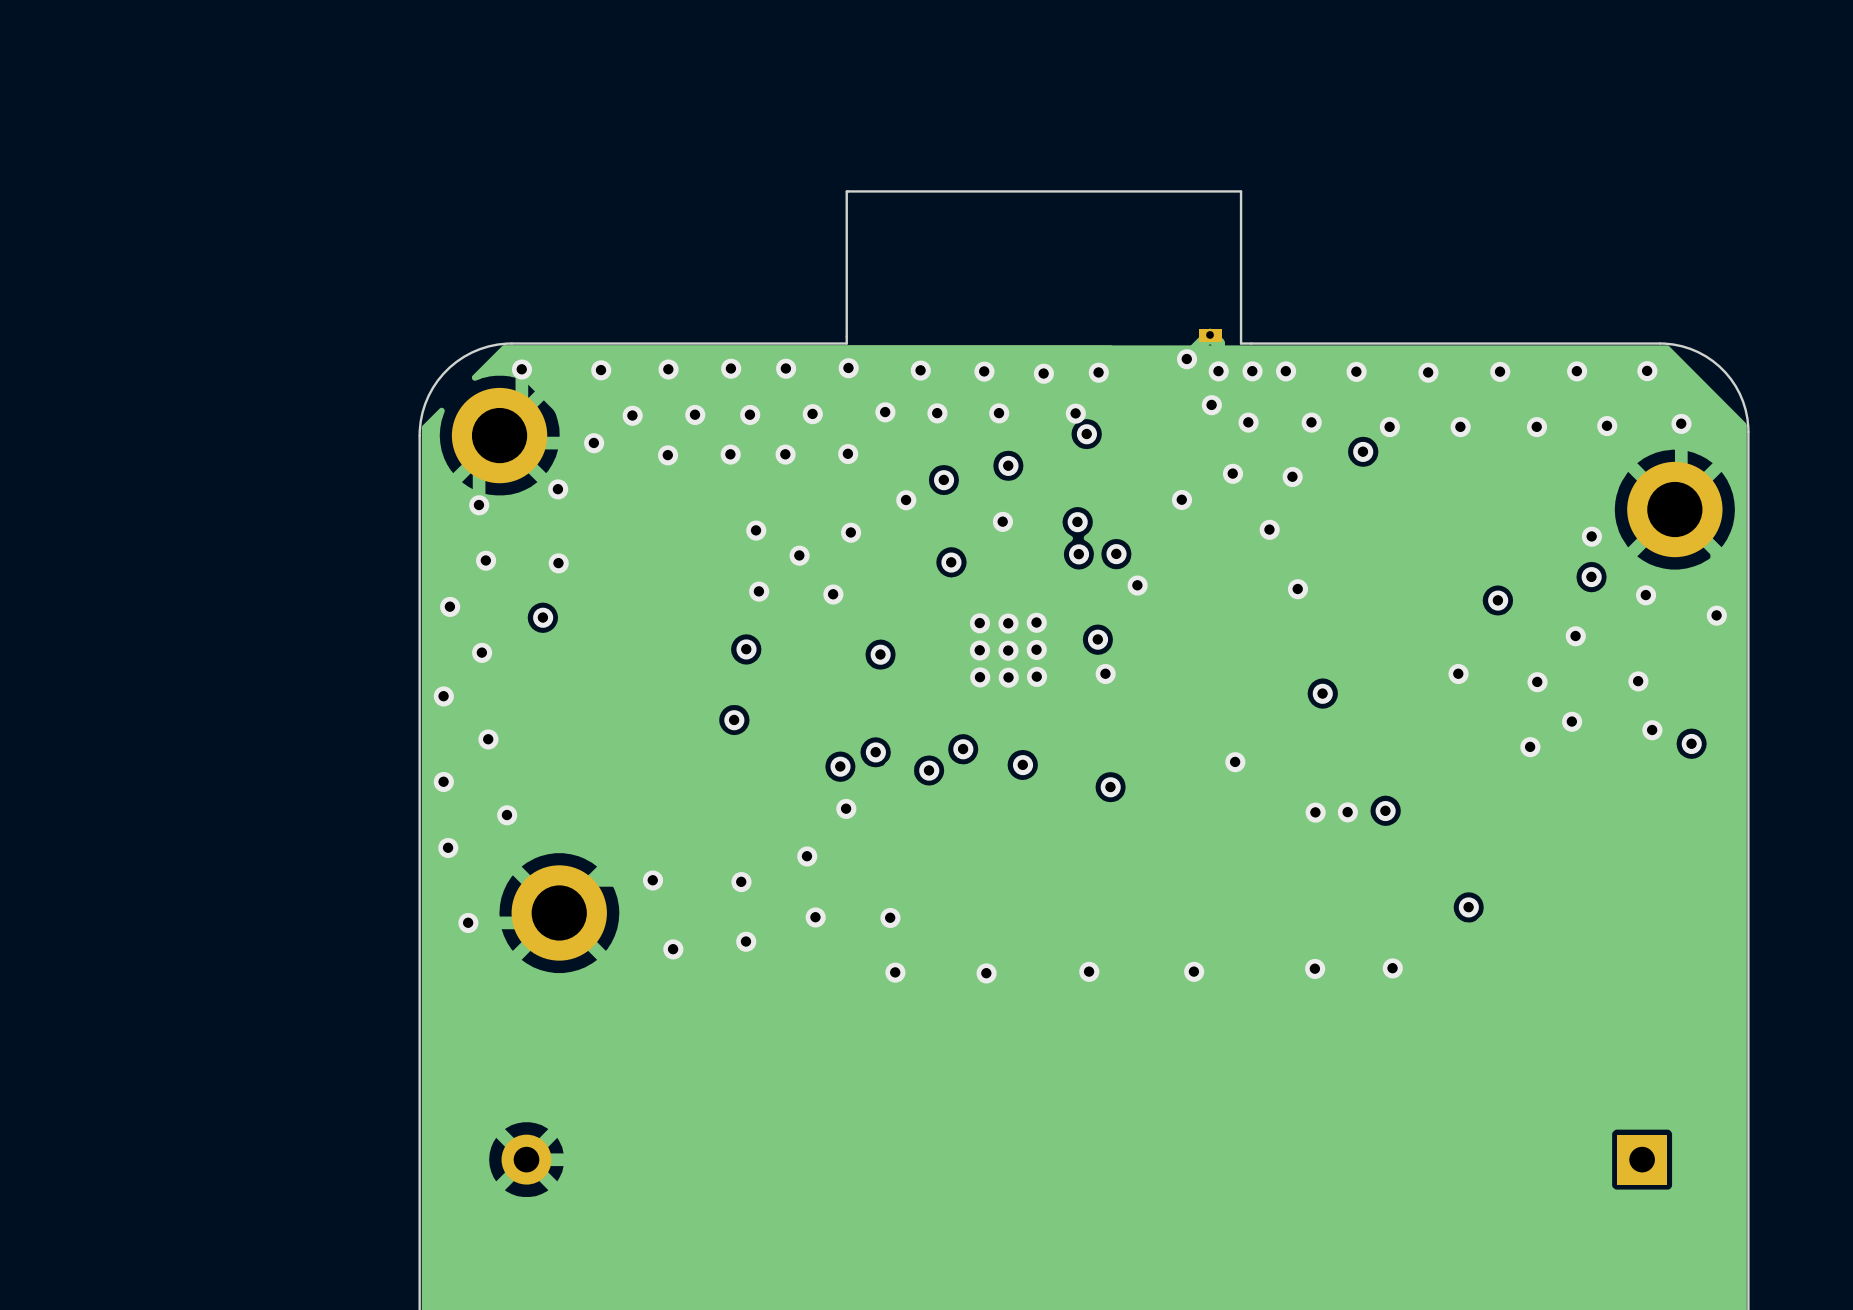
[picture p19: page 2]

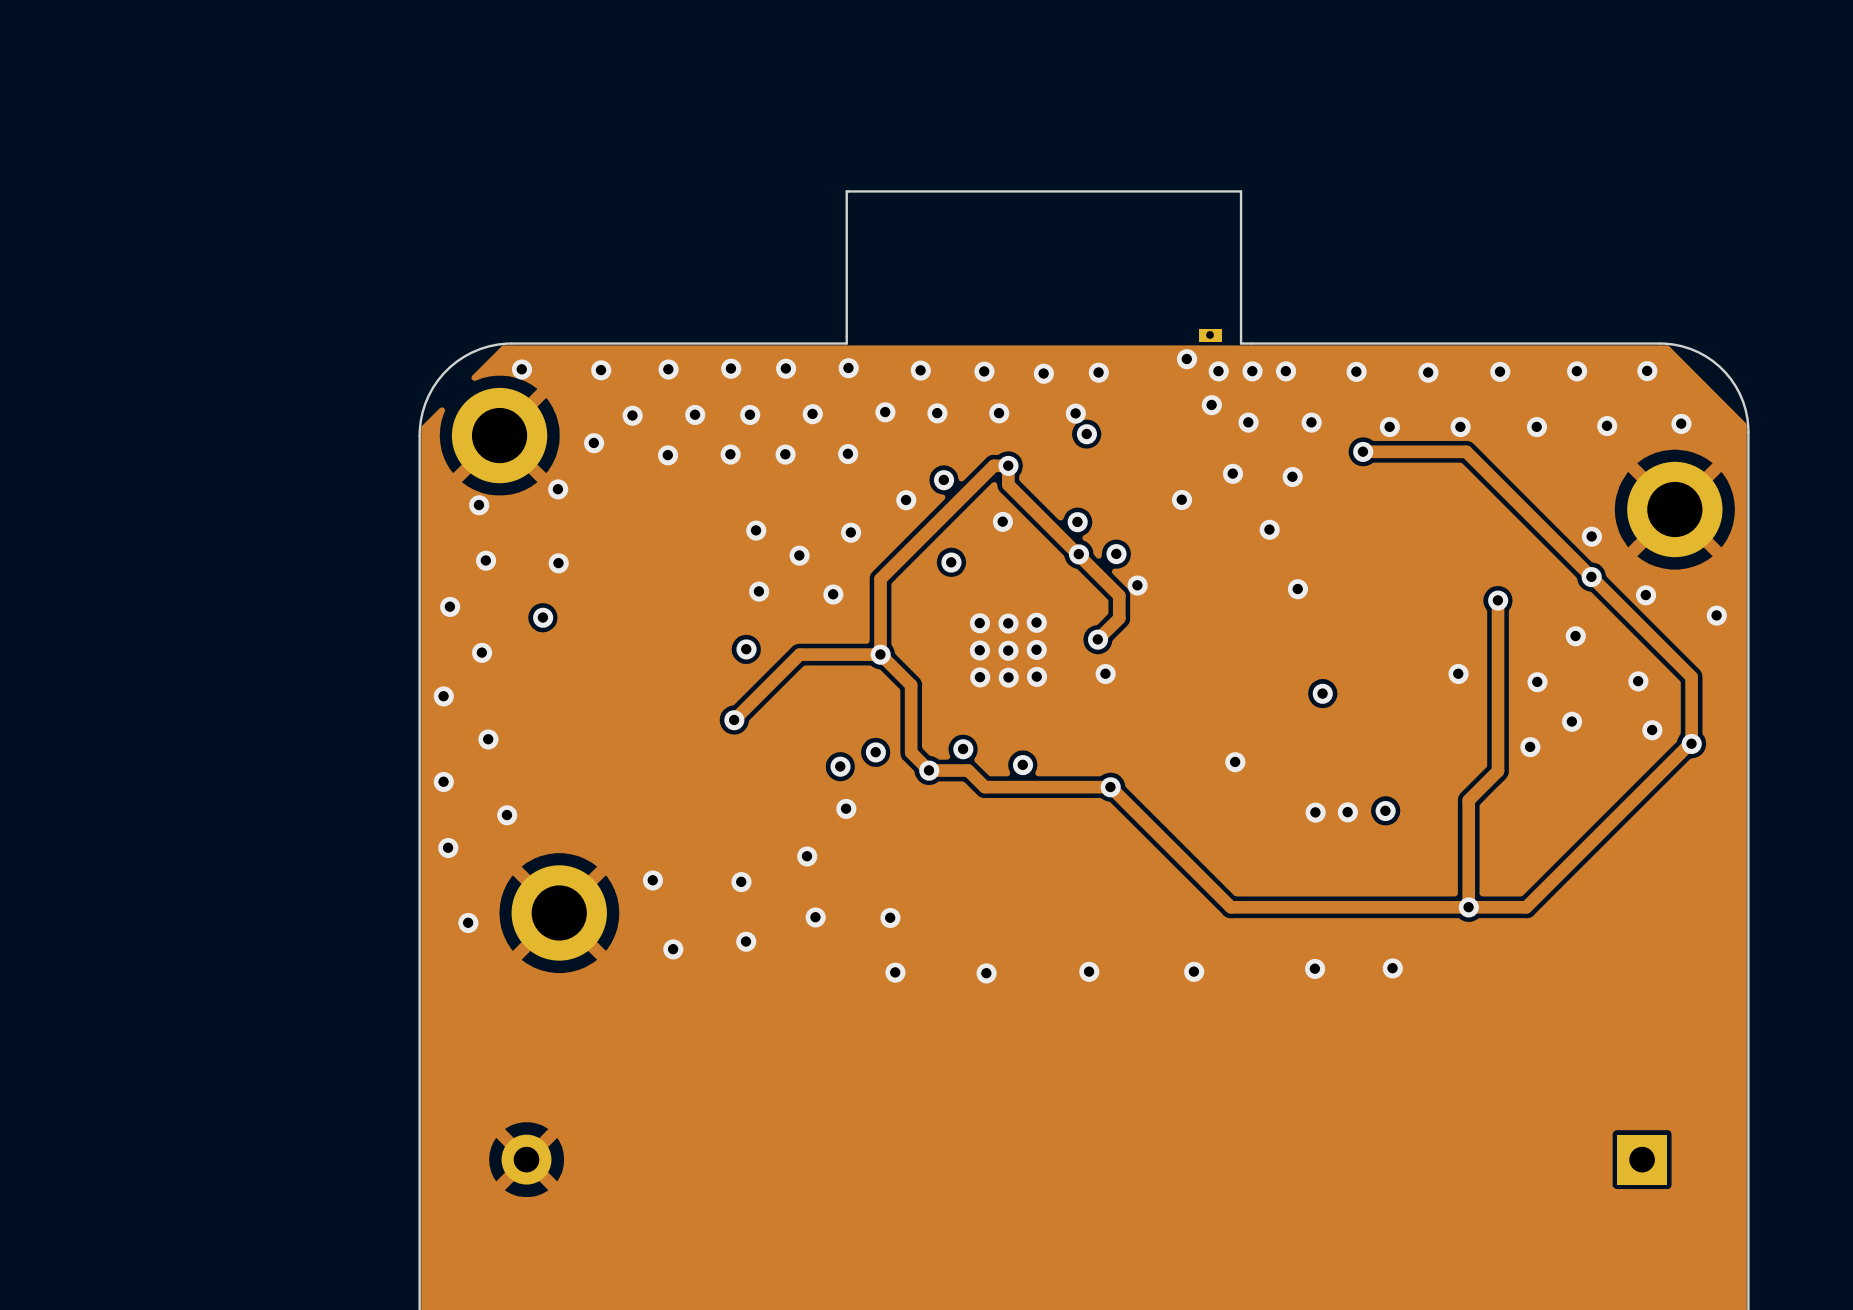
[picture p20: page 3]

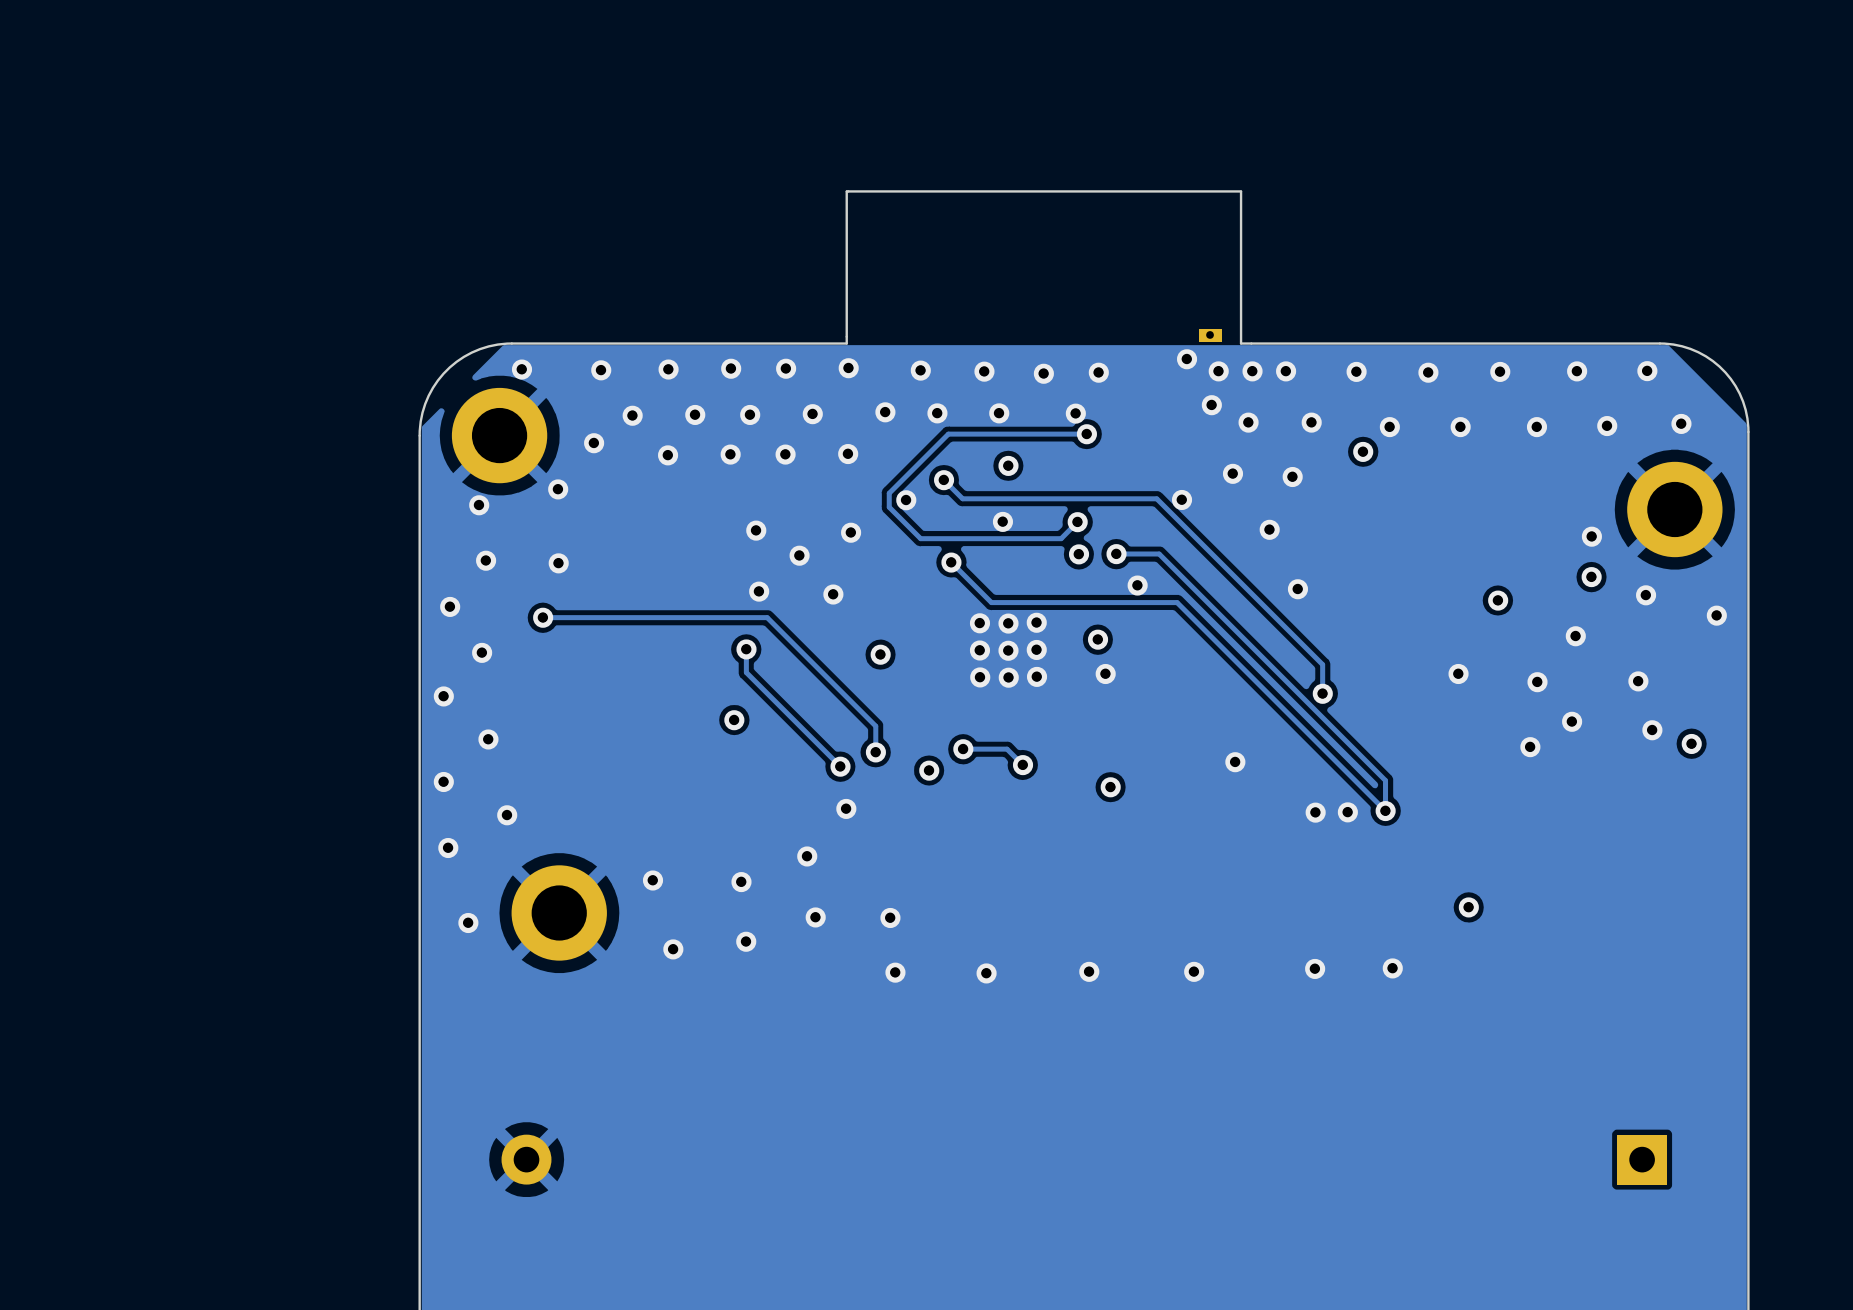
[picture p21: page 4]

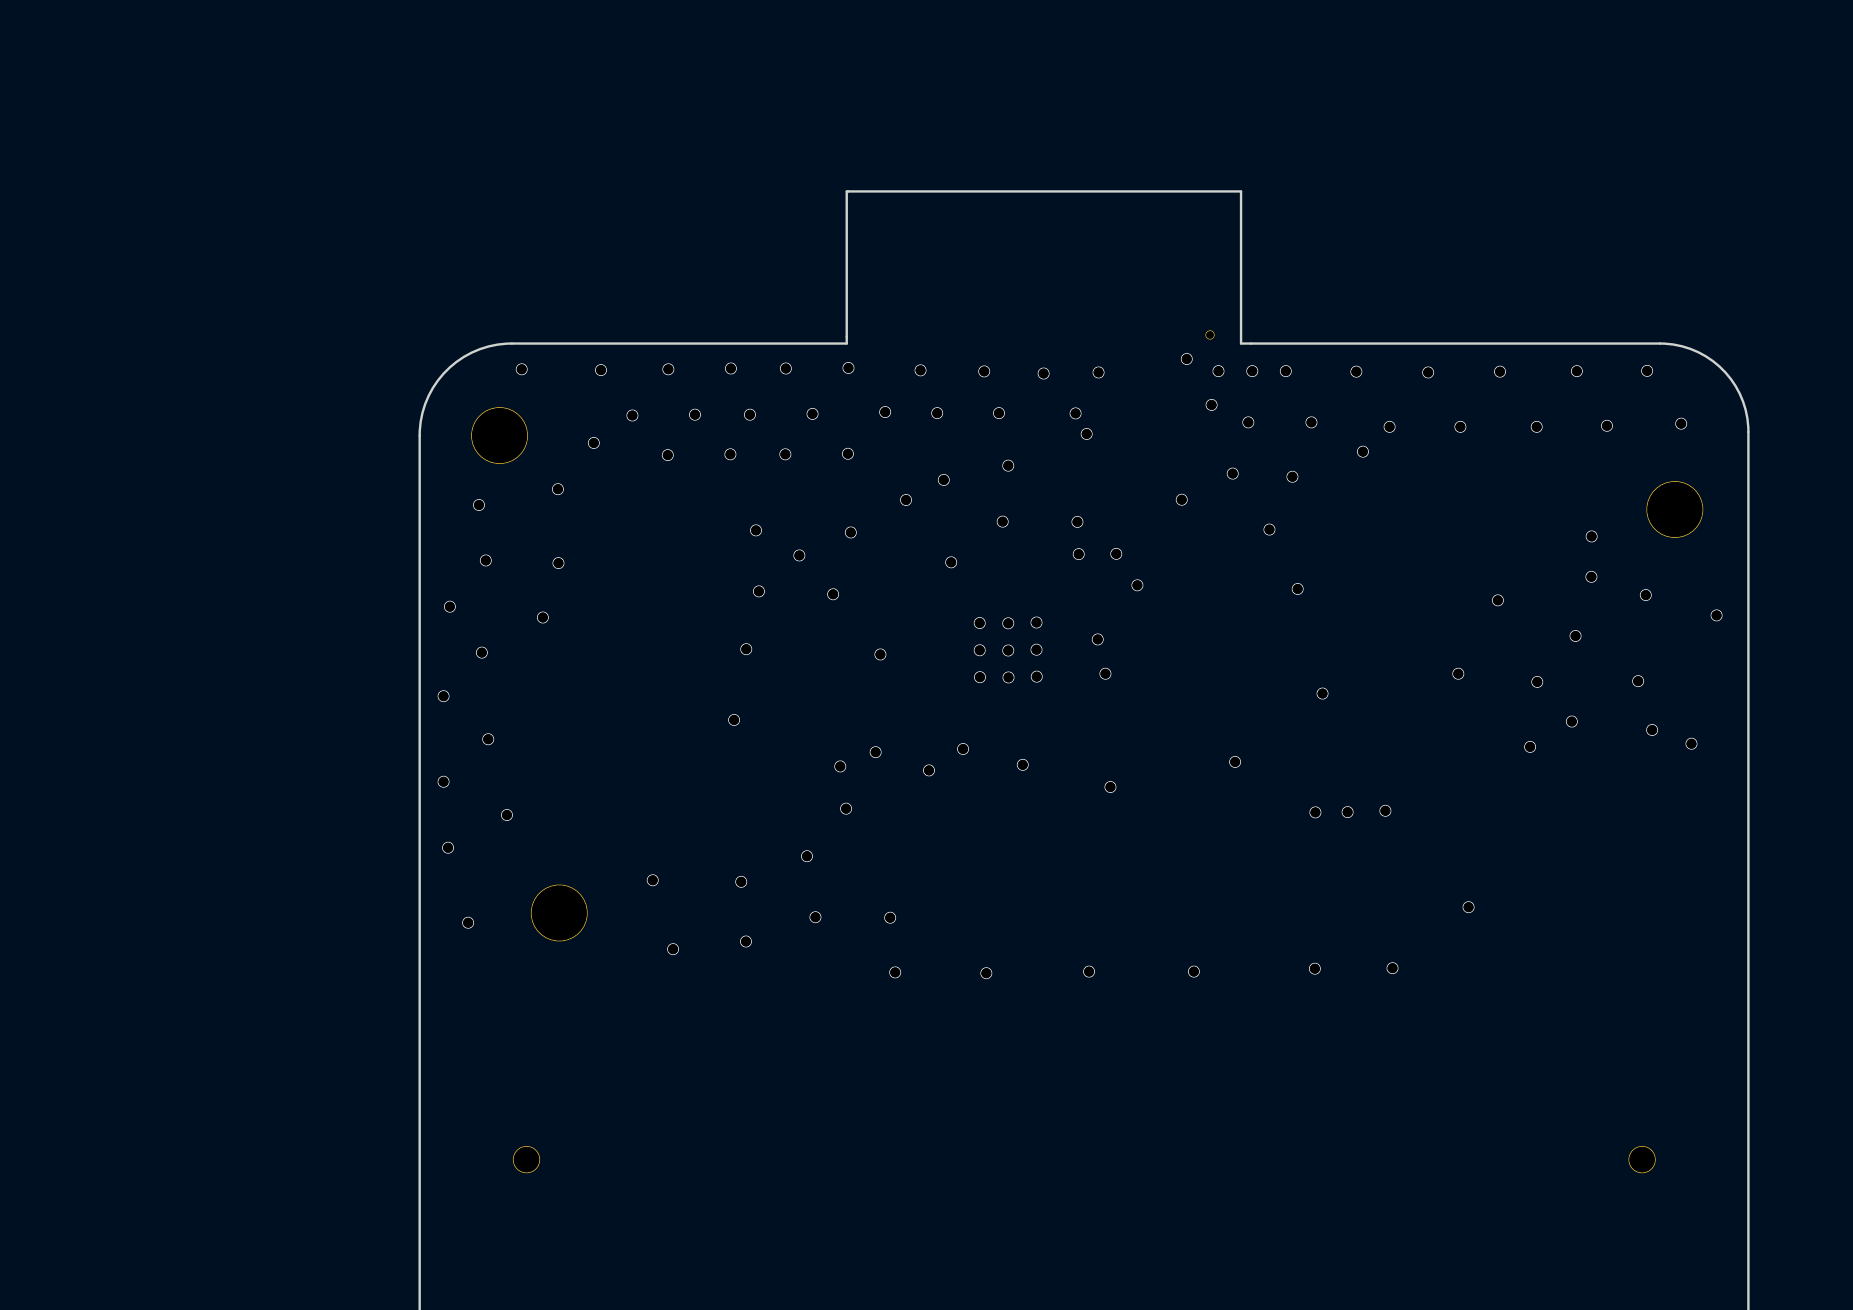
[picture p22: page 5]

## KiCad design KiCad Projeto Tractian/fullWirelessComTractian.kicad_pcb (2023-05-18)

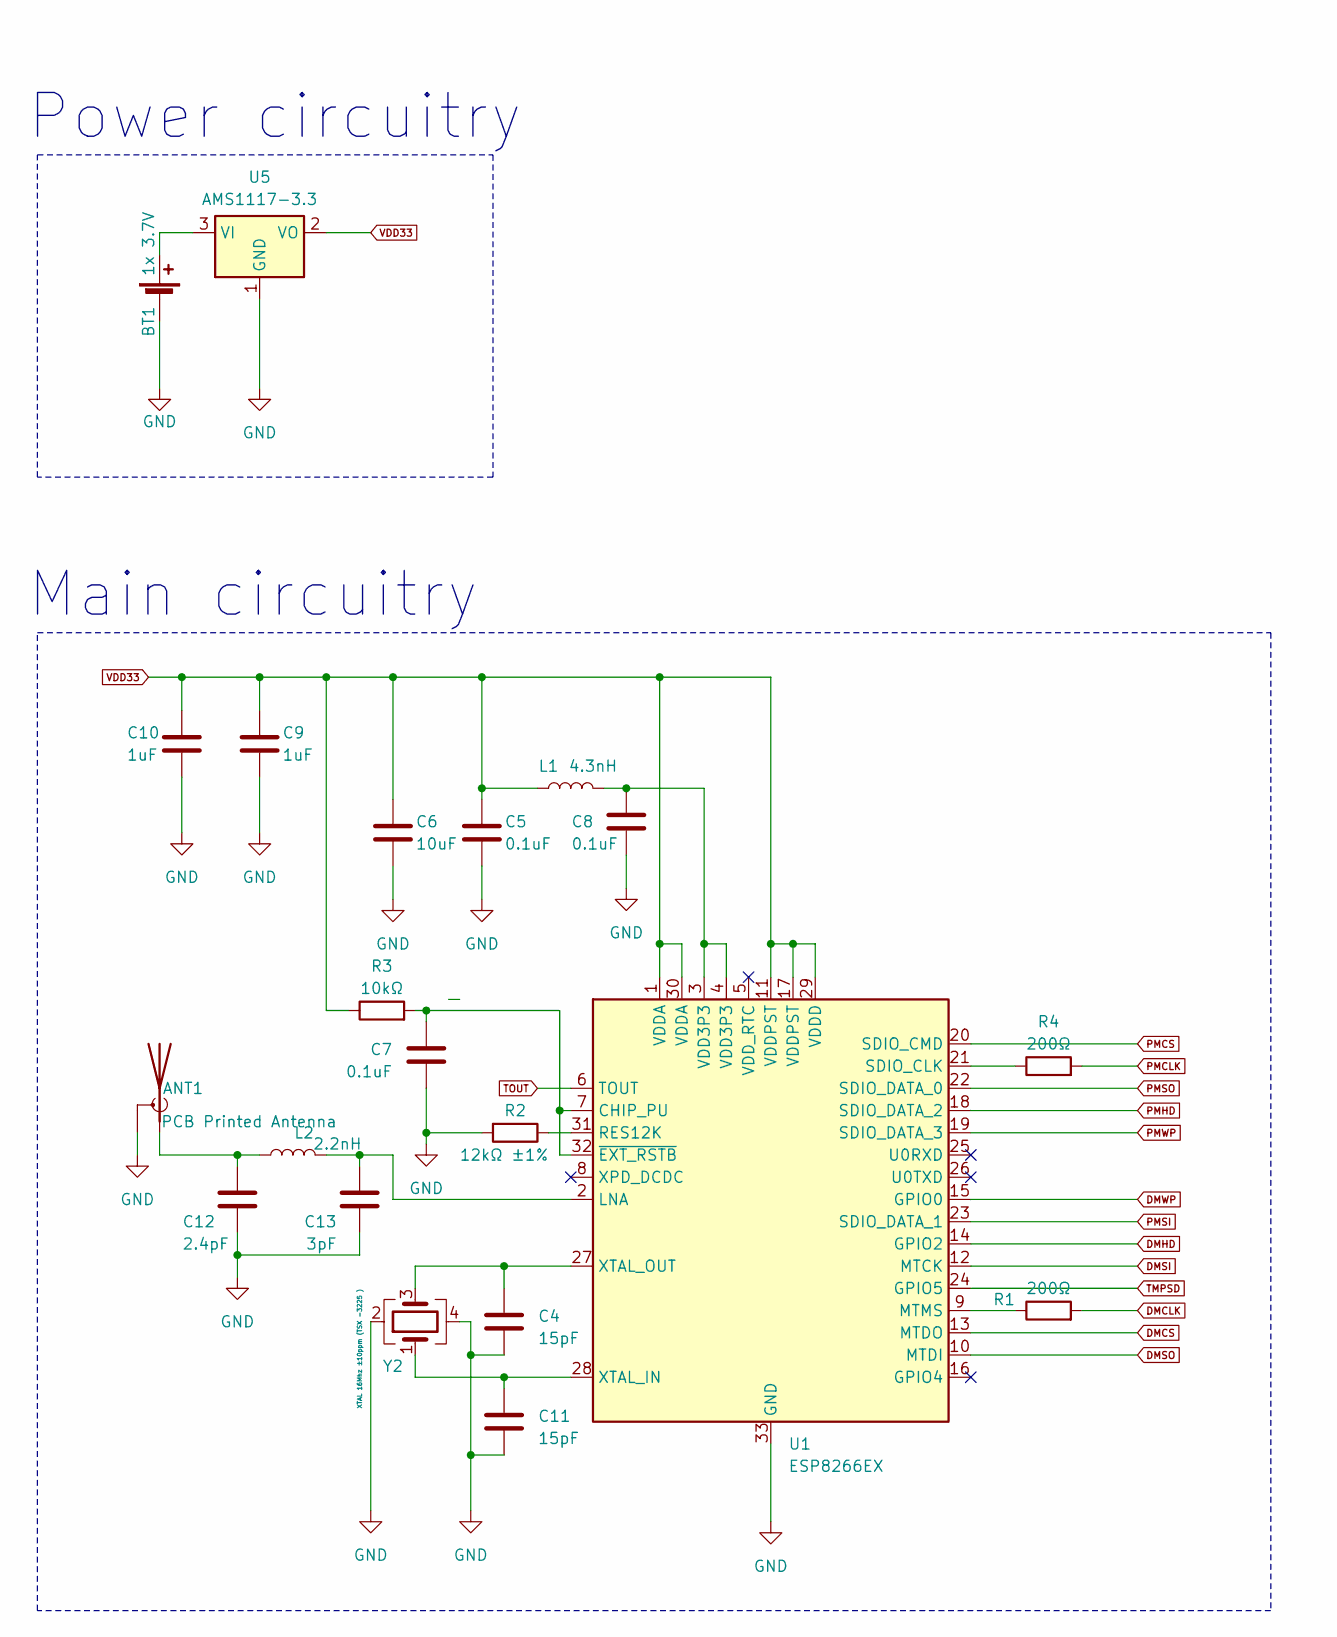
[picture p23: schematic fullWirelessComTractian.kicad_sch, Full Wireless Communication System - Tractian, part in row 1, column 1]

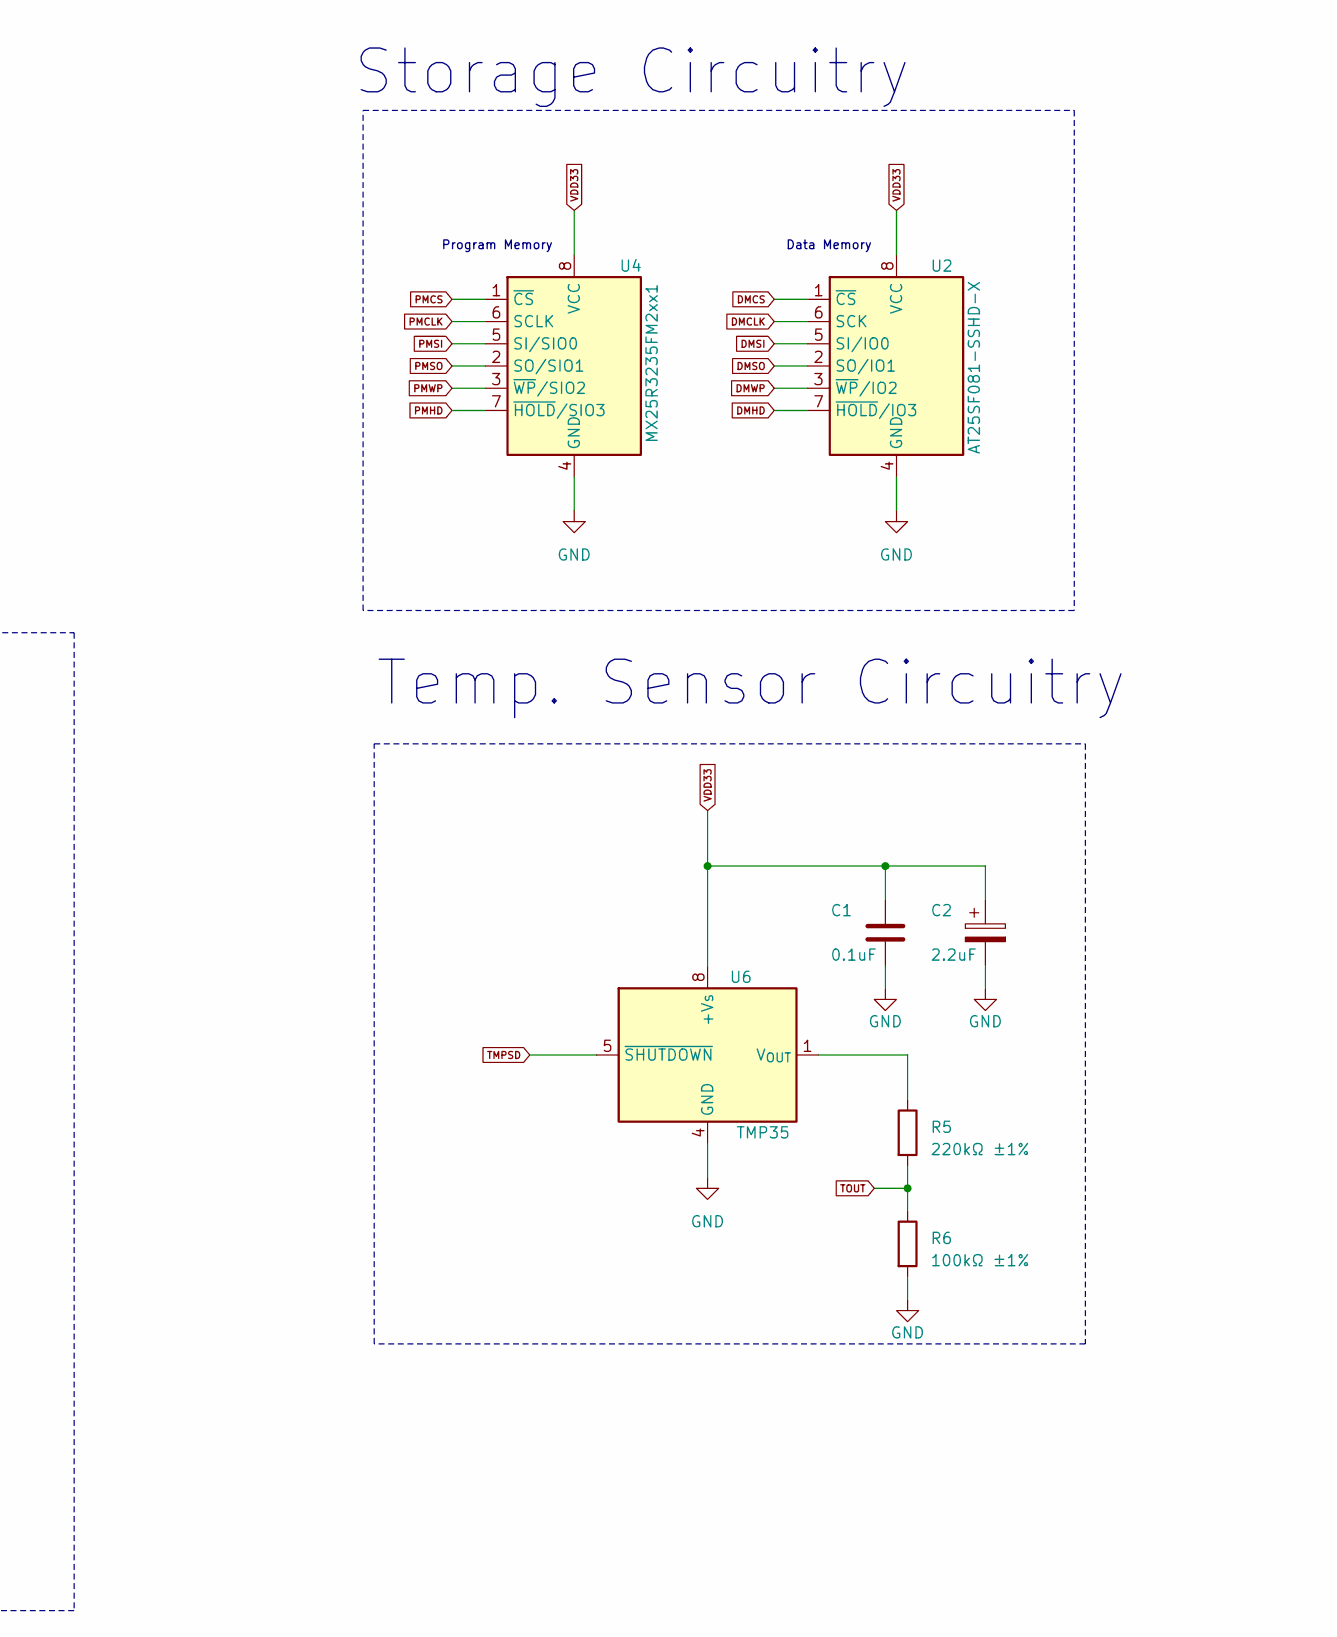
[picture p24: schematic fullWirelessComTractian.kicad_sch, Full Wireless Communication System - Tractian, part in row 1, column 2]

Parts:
ANT1: PCB Printed Antenna; Texas_SWRA117D_2.4GHz_Left
BT1: 1x 3.7V; BatteryHolder_Keystone_2466_1xAAA
C1, C5, C7, C8: 0.1uF; C_0201_0603Metric_Pad0.64x0.40mm_HandSolder
C2: 2.2uF; CP_EIA-1608-08_AVX-J_Pad1.25x1.05mm_HandSolder
C4, C11: 15pF; C_0201_0603Metric_Pad0.64x0.40mm_HandSolder
C6: 10uF; C_0201_0603Metric_Pad0.64x0.40mm_HandSolder
C9, C10: 1uF; C_0201_0603Metric_Pad0.64x0.40mm_HandSolder
C12: 2.4pF; C_0201_0603Metric_Pad0.64x0.40mm_HandSolder
C13: 3pF; C_0201_0603Metric_Pad0.64x0.40mm_HandSolder
L1: 4.3nH; L_0603_1608Metric_Pad1.05x0.95mm_HandSolder
L2: 2.2nH; L_0603_1608Metric_Pad1.05x0.95mm_HandSolder
R1, R4: 200Ω; R_0402_1005Metric_Pad0.72x0.64mm_HandSolder
R2: 12kΩ ±1%; R_0201_0603Metric_Pad0.64x0.40mm_HandSolder
R3: 10kΩ; R_0201_0603Metric_Pad0.64x0.40mm_HandSolder
R5: 220kΩ ±1%; R_0201_0603Metric_Pad0.64x0.40mm_HandSolder
R6: 100kΩ ±1%; R_0201_0603Metric_Pad0.64x0.40mm_HandSolder
U1: ESP8266EX; QFN-32-1EP_5x5mm_P0.5mm_EP3.45x3.45mm
U2: AT25SF081-SSHD-X; SOIC-8_3.9x4.9mm_P1.27mm
U4: MX25R3235FM2xx1; SOP-8_5.28x5.23mm_P1.27mm
U5: AMS1117-3.3; SOT-223-3_TabPin2
U6: TMP35; SOIC-8_3.9x4.9mm_P1.27mm
Y2: XTAL 16Mhz ±10ppm (TSX -3225 ); Oscillator_SMD_SeikoEpson_SG210-4Pin_2.5x2.0mm_HandSoldering

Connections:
DMCLK: R1.2, U2.6 (SCK)
DMCS: U1.13 (MTDO), U2.1 (~CS)
DMHD: U1.14 (GPIO2), U2.7 (~HOLD/IO3)
DMSI: U1.12 (MTCK), U2.5 (SI/IO0)
DMSO: U1.10 (MTDI), U2.2 (SO/IO1)
DMWP: U1.15 (GPIO0), U2.3 (~WP/IO2)
GND: ANT1.2 (Shield), BT1.2 (-), C1.2, C2.2, C4.2, C5.2, C6.2, C7.2, C8.2, C9.2, C10.2, C11.2, C12.2, C13.2, R2.2, R6.2, U1.33 (GND), U2.4 (GND), U4.4 (GND), U5.1 (GND), U6.4 (GND), Y2.2, Y2.4
unnamed: ANT1.1 (A), C12.1, L2.1
unnamed: BT1.1 (+), U5.3 (VI)
unnamed: C8.1, L1.2, U1.3 (VDD3P3), U1.4 (VDD3P3)
unnamed: C7.1, R3.2, U1.7 (CHIP_PU), U1.32 (~EXT_RSTB)
unnamed: C13.1, L2.2, U1.2 (LNA)
unnamed: R1.1, U1.9 (MTMS)
unnamed: R2.1, U1.31 (RES12K)
unnamed: R4.1, U1.21 (SDIO_CLK)
unnamed: C11.1, U1.28 (XTAL_IN), Y2.1
unnamed: C4.1, U1.27 (XTAL_OUT), Y2.3
unnamed: R5.1, U6.1 (V_{OUT})
PMCLK: R4.2, U4.6 (SCLK)
PMCS: U1.20 (SDIO_CMD), U4.1 (~CS)
PMHD: U1.18 (SDIO_DATA_2), U4.7 (~HOLD/SIO3)
PMSI: U1.23 (SDIO_DATA_1), U4.5 (SI/SIO0)
PMSO: U1.22 (SDIO_DATA_0), U4.2 (SO/SIO1)
PMWP: U1.19 (SDIO_DATA_3), U4.3 (~WP/SIO2)
TMPSD: U1.24 (GPIO5), U6.5 (~SHUTDOWN)
TOUT: R5.2, R6.1, U1.6 (TOUT)
VDD33: C1.1, C2.1, C5.1, C6.1, C9.1, C10.1, L1.1, R3.1, U1.1 (VDDA), U1.11 (VDDPST), U1.17 (VDDPST), U1.29 (VDDD), U1.30 (VDDA), U2.8 (VCC), U4.8 (VCC), U5.2 (VO), U6.8 (+Vs)

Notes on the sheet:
Temp. Sensor Circuitry
Storage Circuitry
Program Memory
Data Memory
Main circuitry
Power circuitry

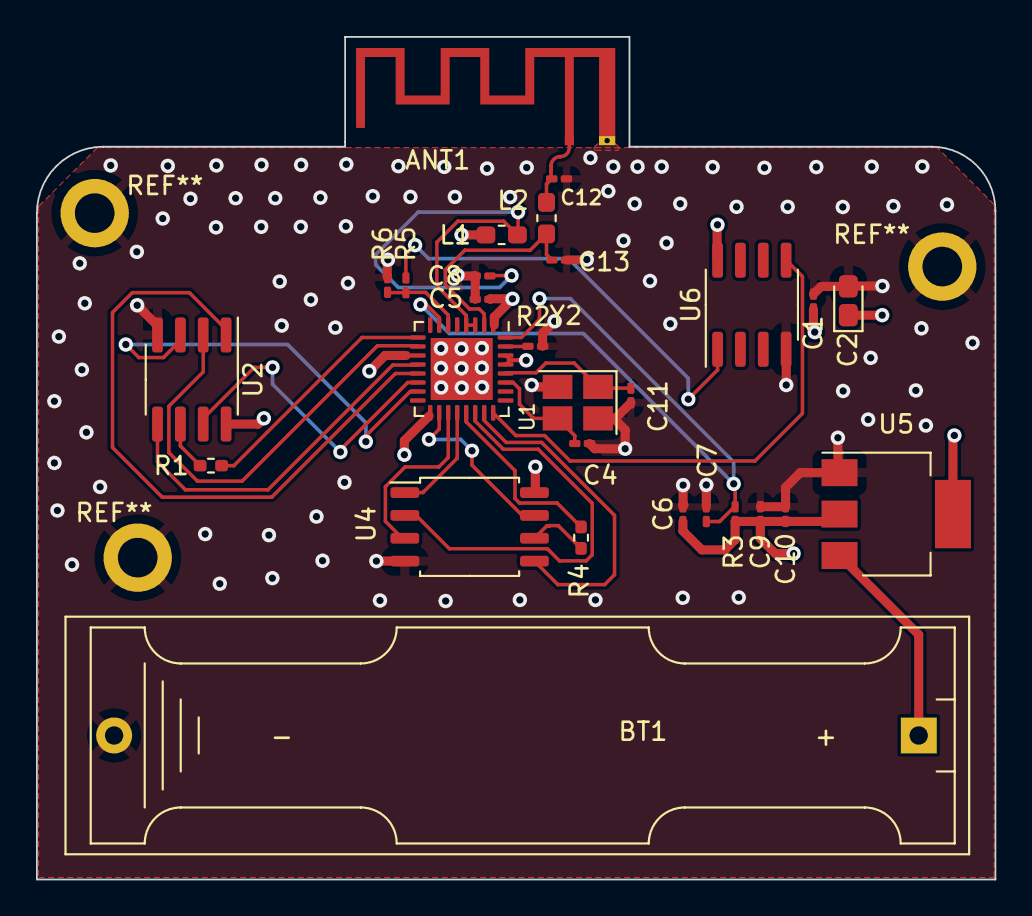
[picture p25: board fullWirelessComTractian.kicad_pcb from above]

Board: 4 copper layers, 53.3 x 46.8 mm, 28 parts (0 on the bottom side), 27 nets.

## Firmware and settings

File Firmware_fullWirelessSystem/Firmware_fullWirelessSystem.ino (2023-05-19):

/*********************************************************************************************************************************************************

------- Author: Caio Dutra

------- Date: 05-17-2023

##### Full Wireless Communication System Project - Tractian Firmware Eginneer Interview #####

The ultimate goal of this firmware is to establish a complete wireless communication 
between a data collecting station (ESP8266EX) and an access point located 100m away 
using the WiFi protocol. The hardware collects data on-site, stores it with a size of 500kB, 
and then sends it to the access point.

For the purpose of data collection, a temperature measuring circuit was implemented
on the hardware using a TMP36 IC. A linear time-invariant system, namely the Moving 
Average Filter, is required to ensure that the measured temperature remains in a stable
state when it is saved in the flash data memory integrated into the hardware.

##
Note: The choice of the TMP36 IC is due to the fact that this sensor has a shutdown state
when its usage is not required. In this situation, the IC operates with currents of 0.5uA.
This ensures energy savings as the system operates remotely using batteries. Additionally, 
during its active state, the TMP36 operates with currents of 50uA, which are also considered
low for the application in question.

For the WiFi protocol, it is used the "ESP8266WiFi.h" library licensed under LGPL (Lesser General
Public License) Version 2.1, which in broad terms it can be interpreted as follows:

      "Primarily used for software libraries, the GNU LGPL 
       requires that derived works be licensed under the same license, but works that only link to it do not
       fall under this restriction."

The candidate chose to use this library because he doesn't have solid 
knowledge of the WiFi protocol (from the physical layer to the application layer) to develop his own
library (or subroutines). A full copy of the LGLP Ver 2.1 can be seen at: https://github.com/esp8266/Arduino/blob/master/LICENSE


For the communication between the microcontroller and the Flash Data Memory, it is used the SPI 
communication protocol.


## This is the final version of the firmware (yet to be revised). 

**********************************************************************************************************************************************************/

/* -#-#--#-#--#-#--#-#--#-#--#-#--#-#--#-#--#-#--#-#--#-#--#-#--#-#--#-#--#-#--#-#--#-#--#-#--#-#--#-#--#-#--#-#- */


/*******************************
*                              *
*           Libraries          *
*                              *
********************************/


#include <ESP8266WiFi.h>

WiFiClient _hostClient; // creates an instance of WifiClient for the host to be connected


/********     END    ***********
*                              *
*           Libraries          *
*                              *
********************************/




/* -#-#--#-#--#-#--#-#--#-#--#-#--#-#--#-#--#-#--#-#--#-#--#-#--#-#--#-#--#-#--#-#--#-#--#-#--#-#--#-#--#-#--#-#- */


/*******************************
*                              *
*  Pin Constants Definitions   *
*                              *
********************************/



/* AS we're using the NodeMCU 1.0 board to record the Program on ESP8266EX
it is needed to use the GPIO's definitions for its board to match our own
hardware. For this, we use the IO Number as the GPIO Number. For instance,
if we want to use the GPIO14 as output, we declare "pinMode(14,OUTPUT);"
*/

// Data Memory GPIO's definitions for SPI comm:
#define DMCS 15 // Data Memory Chip/Slave Select - Pin 13 on ESP8266EX -> (MTDO) GPIO15
#define DMCLK 14 // Data Memory Serial Clock - Pin 9 on ESP8266EX -> (MTMS) GPIO14
#define DMSI 13 // Data Memory SI (slave data input) (MOSI) - Pin 12 on ESP8266EX -> (MTCK) GPIO13
#define DMSO 12 // Data Memory SO (slave data output) (MISO) - Pin 10 on ESP8266EX -> (MTDI) GPIO12
#define DMWP 0 // Data Memory Write Protect - Pin 15 on ESP8266EX -> (GPIO0) GPIO0
#define DMHD 2 // Data Memory Hold - Pin 14 on ESP8266EX -> (GPIO2) GPIO2

// SPI delay for 8Mhz comm (Flash Data Memory operates up to 8Mhz for single IO mode)
// For we are using bit banging data, a (way) lower frequency will be used.
// Acording to Arduino Reference, for 'delayMicroseconds(t);' operates very accurately 
// for a minimum valeu of t = 3 (3us). Being so, The period of the SCLK shall be 6us,
// which leads to f = 166.666 kHz. That being said, every 3 seconds or so 500,000
// samples of temperature will be collected. This barely has any practical uses,
// but the principle of the challenge stands.
#define Half_SPI_Period 3 // for f = 8MHz , T = 6us


// Temperature Sensor GPIO definition
#define Temp_Sensor_ADC_Pin 17 // TMP35 Vout - Pin 6 on ESP8266EX -> (TOUT) ADC_in | On NodeMCU it is mapped to pin 17
#define Temp_Sensor_Shutdown_Pin 5 // TMP35 SHUTDOWN - Pin 24 on ESP8266EX -> (GPIO5) GPIO5




/********     END    ***********
*                              *
*  Pin Constants Definitions   *
*                              *
********************************/


/* -#-#--#-#--#-#--#-#--#-#--#-#--#-#--#-#--#-#--#-#--#-#--#-#--#-#--#-#--#-#--#-#--#-#--#-#--#-#--#-#--#-#--#-#- */



/*******************************
*                              *
*  Declaration of constants    *
*                              *
********************************/

const char* SSID = "Fake_WiFi_Net_To_Connect"; // service set identifier of the AP to be connected

const char* PSSWRD = "Fake_WiFi_Net_Password"; // net password of the AP to be connected

const char* HOST = "192.13.14.5/temperature_log_files"; // Fake URL to send data (500kB file)

const int _httpPort = 80; // HTTP Port to be used

/********     END    ***********
*                              *
*  Declaration of constants    *
*                              *
********************************/





/* -#-#--#-#--#-#--#-#--#-#--#-#--#-#--#-#--#-#--#-#--#-#--#-#--#-#--#-#--#-#--#-#--#-#--#-#--#-#--#-#--#-#--#-#- */


/*******************************
*                              *
*    Declaration of Arrays     *
*                              *
********************************/

// Global Array to store 256 Stable Temperature Readings (later to be used on Data Memory Write)
byte Temp_Vector[256]; // records 256 sample of stables temp measurements to record on a page on Data Memory
byte Temp_Buffer[50]; // Buffer to stores 50 samples of intantaneous Temperature readings

// 3Byte Memory Address
byte _addressBytes[3];

// 1024 array for reading from data memory and sending via WiFi (total of 500 packets of 1024 bytes to be sent -> 500kB)
byte _readData[1024];


/********     END    ***********
*                              *
*    Declaration of Arrays     *
*                              *
********************************/



/* -#-#--#-#--#-#--#-#--#-#--#-#--#-#--#-#--#-#--#-#--#-#--#-#--#-#--#-#--#-#--#-#--#-#--#-#--#-#--#-#--#-#--#-#- */




/*******************************
*                              *
*   Unislot vars Definitions   *
*                              *
********************************/


// Memory Address Word
unsigned long ADDRESS = 0x000000; // By our definition, Memory Write starts at address 0
int _packetCount = 0; // count var for Page Program


int _numOfTries = 0; // starts with 0 - count the number of times the station tried to connect with to host before it gives up and leads to another set of collecting tempereture values
// int _connectionSuccess; // indicates if the connection to the host was sucessful (1) or not (0)


int p; // count var for 500kB file (counts the number os 1024bytes packets sent to the host - total of 512,000 bytes)
int q; //count var (parameter of _readData) for 1024 bytes to be sent

/********     END    ***********
*                              *
*   Unislot vars Definitions   *
*                              *
********************************/




/* -#-#--#-#--#-#--#-#--#-#--#-#--#-#--#-#--#-#--#-#--#-#--#-#--#-#--#-#--#-#--#-#--#-#--#-#--#-#--#-#--#-#--#-#- */





/*******************************
*                              *
* Declaration of Subroutines   *
*                              *
********************************/

// Declaration of function that creates an array with the 3 addresses bytes for the Data memory
void create_Addres_Bytes (unsigned long Address);

// Declaration of the Reading of Temperature Reading Routine
void Temp_Read(void);

// Declaration of bit banging SPI subroutine | Mode 0 | MSB First
byte SPI_BB(byte _send8bitData);


// Declaration of the Data Memory Page Program Function
void Data_Memory_Write(byte _writeAddress[3], byte _writeByte[256]);

// Declaration of Data Read Function
void Data_Memory_Read(byte _readAddress[3]);

//Declaration of the Erase Chip Instruction Function
void Memory_Erase(void);


/********     END    ***********
*                              *
* Declaration of Subroutines   *
*                              *
********************************/


/* -#-#--#-#--#-#--#-#--#-#--#-#--#-#--#-#--#-#--#-#--#-#--#-#--#-#--#-#--#-#--#-#--#-#--#-#--#-#--#-#--#-#--#-#- */



void setup() {
  
  // defining the 4xIO of the Data Memory SPI and some of its states
  pinMode(DMSO, INPUT); 
  pinMode(DMSI, OUTPUT);
  pinMode(DMCLK, OUTPUT);
  pinMode(DMCS, OUTPUT);
  digitalWrite(DMCS, HIGH); // Set Slave Select to HIGH, so it is guranteed to be inactive
  digitalWrite(DMCLK, LOW); // Gurantees SCLK is set to LOW so when the COM starts the clock is on idle mode

  // defitions of the Hold and WP Pins of Data Memory
  digitalWrite(DMHD, HIGH); // sets the Hold Pin on the Data Memory to HIGH, so its inactive
  digitalWrite(DMWP, HIGH); // sets the Write Protect Pin on the Data Memory to HIGH, so its inactive

  //definition of the SHUTDOWN pin of TMP35
  pinMode(Temp_Sensor_Shutdown_Pin,OUTPUT);

  delay(1000); // For powering guarantees, wait 1s for stabilization of whole circuit (data memory, temp sensor, etc) 

}

void loop() {

 
  /* -#-#--#-#--#-#--#-#--#-#--#-#--#-#--#-#--#-#--#-#--#-#--#-#--#-#--#-#--#-#--#-#--#-#--#-#--#-#--#-#--#-#--#-#- */

  // First firmware assignment:
  /*************************************************
  *                                                *
  * Collects 512,000 (500kB) values of temperature *
  * and stores it on the Data Memory               *
  *                                                *
  *************************************************/


  Memory_Erase(); // Erases entire memory chip for a new temperature recording cycle on the loop
  delay(10); // little delay so the Erase Chip opcde is properly executed 

  
  digitalWrite(Temp_Sensor_Shutdown_Pin,HIGH); // Enables the TMP35 to operate
  delay(1); // little delay so the TMP35 is functional

  // Writes 2000 Packets of 256Bytes (500kB) of Temperature values on Data Memory
  for(_packetCount = 0; _packetCount< 2000; _packetCount++){

    Temp_Read(); // reads 256 values of temperature

    create_Addres_Bytes(ADDRESS); // creates the 3Byte address from a 24bit word, to be used on data record

    Data_Memory_Write(_addressBytes, Temp_Vector); // Stores 256 values (Bytes) of data (temperature) on Data Memory

    ADDRESS += 0x100; // Sums 256 to the address word, for new start address

  }
  digitalWrite(Temp_Sensor_Shutdown_Pin,LOW); // disables the TMP35 and puts it on ultra low current comsuption mode (maximum of 0.5uA)

  ADDRESS = 0x000000; // Resets the Address to 0 - data memory read and transmission by WiFi.


  /****************      END      ******************
  *                                                *
  * Collects 512,000 (500kB) values of temperature *
  * and stores it on the Data Memory               *
  *                                                *
  *************************************************/

  /* -#-#--#-#--#-#--#-#--#-#--#-#--#-#--#-#--#-#--#-#--#-#--#-#--#-#--#-#--#-#--#-#--#-#--#-#--#-#--#-#--#-#--#-#- */


  // Second firmware assignment:
  /**********************************************
  *                                             *
  * Reads 512,000 (500kB) values of temperature *
  * from data memory and sends via WiFi.        *
  *                                             *
  ***********************************************/

  //if ESP is disconnected from the AP, reconects it
  if(WiFi.status() != WL_CONNECTED){

    WiFi.begin(SSID,PSSWRD); // set the SSID and password to connect on the AP
    while(WiFi.status() != WL_CONNECTED){} // wait until the ESP connects to the AP, otherwise doesn't proceed
    delay(500); // wait a little bit so the connection is stable

  }

  // _hostClient.setInsecure(); // for simplicity, disables SSL certificate as we're assuming the URL to send data is in localhost server, forinstance
  // tries to connect 10 times to the host before gives up and restart the temperature collecting process
  while( (_hostClient.connect(HOST, _httpPort) == false) && (_numOfTries < 10)){

    delay(5000);// waits five second
    _numOfTries++; // increments the number of times that the station tried to connect to the host
  }


  //tests if the the connection to the host was stabilshed within less than 10 tries. If so, will send the 500kB file to the Host
  if(_numOfTries < 10){


    //continuously check if the host client still connected in order to send data and do not waste energy/time with RF transmissions
    while(_hostClient.connected()){

       
      // loops 500 times to sent 500kB files (1024byte packets each time) 
      for(p = 0; p< 500; p++){

        create_Addres_Bytes(ADDRESS); // creates the 3Byte address from a 24bit word, to be used on data read
        Data_Memory_Read(_addressBytes); // creates the 1024 byte array to be sent
        for(q = 0; q < 1024; q++){

          _hostClient.write(_readData[q]); // sends the qth byte of the pth packet of data

        }

        ADDRESS += 0x400; // sums 1024 to the addreess to take next four pages of temperature values

      }

      

    }

    // if the transmission ocurred successfuly (whole packt of 500kB), then closes the connection with the host
    if(_hostClient.connected()){

      _hostClient.print("GET / HTTP/1.1/\r\n"); // \r indicates an end of command, while \n creates a new line
      _hostClient.print("Host: 192.13.14.5/temperature_log_files\r\n");
      _hostClient.print("Connection: close\r\n\r\n");

    }

    WiFi.disconnect(); // turns the connection with the AP off to save energy.

    _numOfTries = 0; // resets try-to-connect counting var;

    ADDRESS = 0x000000; // Resets the Address to 0 - temperature log write on data memory.

  }

  /***************     END     ******************
  *                                             *
  * Reads 512,000 (500kB) values of temperature *
  * from data memory and sends via WiFi.        *
  *                                             *
  ***********************************************/


  /* -#-#--#-#--#-#--#-#--#-#--#-#--#-#--#-#--#-#--#-#--#-#--#-#--#-#--#-#--#-#--#-#--#-#--#-#--#-#--#-#--#-#--#-#- */


}









/* -#-#--#-#--#-#--#-#--#-#--#-#--#-#--#-#--#-#--#-#--#-#--#-#--#-#--#-#--#-#--#-#--#-#--#-#--#-#--#-#--#-#--#-#- */

/************************
********   SPI   ******** 
*************************/


// Bit banging SPI subroutine (mode 0) - MSB First:
byte SPI_BB(byte _sendByte){


  byte _receivedByte = 0;
  byte  k = 0; // auxiliar couting byte var

  for(k = 0x80; k != 0; k /= 2) // \frac{k}{2} shifts the kth bit to the right >>
  {

    if ((k & _sendByte) !=0x00){ // tests if the kth send bit is 1 or 0 with the k mask and Writes the kth bit of the sending word on the MOSI PIN
      digitalWrite(DMSI,HIGH);
    }   
    else {
      digitalWrite(DMSI,LOW);
    }

    digitalWrite(DMCLK, HIGH); // Sets SCK (Clock) to HIGH so the slave reads the DMSI GPIO on rising edge of clock
    delayMicroseconds(Half_SPI_Period); // COM delay
    digitalWrite(DMCLK, LOW); // Sets SCK (Clock) to LOW so the slave sends the kth bit to the master
      
    if(digitalRead(DMSO) == HIGH){ // if the Master Input is in HIGH state (a bit has been sent), then stores this bit in the kth position of the received var
      _receivedByte |= k ;
    } 
   delayMicroseconds(Half_SPI_Period); // COM delay
   
      
  }

  
  return _receivedByte; // returns the received byte

}


/*******   END   ********
********   SPI   ******** 
*************************/



/* -#-#--#-#--#-#--#-#--#-#--#-#--#-#--#-#--#-#--#-#--#-#--#-#--#-#--#-#--#-#--#-#--#-#--#-#--#-#--#-#--#-#--#-#- */







/************************
**** Memory Write    **** 
*************************/
// Writes 256 Bytes of memory per page (full page write)
// 3 Bytes Address are needed as reference to start recording,
// in the form _writeAddress[B2 B1 B0], B2 being Most Significative Byte

void Data_Memory_Write(byte _writeAddress[3], byte _writeByte[256]){

  byte WREN = 0x06; // Write enable instruction (06h)

  byte dummy = 0; // dummy byte var as the Writing process doesn't return any data

  byte PP_INSTRUCTION = 0x02; // Page Program instruction 

  dummy = 0; // 
  int i = 0; // counting var


  // Write Enable command:
  digitalWrite(DMCS,LOW); // sets the slave to active mode
  digitalWrite(DMCLK,LOW); // initialize SCLK at idle state
  delayMicroseconds(Half_SPI_Period); // COM delay for half of a period
  dummy = SPI_BB(WREN); // execute the Write Enable instruction
  digitalWrite(DMCS,HIGH); // resets the slave to disabled mode
  delayMicroseconds(50); // 50us delay so the Page program command can be accurately interpreted after the WREN instruction 



  digitalWrite(DMCS,LOW); // sets the slave to active mode
  digitalWrite(DMCLK,LOW); // initialize SCLK at idle state
  delayMicroseconds(Half_SPI_Period); // COM delay for half of a period
  dummy = SPI_BB(PP_INSTRUCTION); // execute the Page Program instruction

  // sends the start page address, Address_MSB first
  for(i = 2; i>= 0; i--){

    dummy = SPI_BB(_writeAddress[i]);

  }

  //sends the 256 Bytes to be stored
  for(i = 0; i<256; i++){ // runs 256 times
  
    dummy = SPI_BB(_writeByte[i]);

  } 
  digitalWrite(DMCS,HIGH); // resets the slave to disabled mode

}


/*******   END    ********
**** Memory Write     **** 
*************************/


/* -#-#--#-#--#-#--#-#--#-#--#-#--#-#--#-#--#-#--#-#--#-#--#-#--#-#--#-#--#-#--#-#--#-#--#-#--#-#--#-#--#-#--#-#- */






/*************************
****   Memory Read    **** 
*************************/
// Reads 1024 Bytes of memory per call
// 3 Bytes Address are needed as reference to start reading,
// in the form _readAddress[B2 B1 B0], B2 being Most Significative Byte


void Data_Memory_Read(byte _readAddress[3]){


  byte READ_INSTRUCTION = 0x03; // Read opcode 

  byte dummy = 0; // dummy byte for SI and SO
  int i = 0; // counting var


  digitalWrite(DMCS,LOW); // sets the slave to active mode
  digitalWrite(DMCLK,LOW); // initialize SCLK at idle state
  delayMicroseconds(Half_SPI_Period); // COM delay for half of a period

  dummy = SPI_BB(READ_INSTRUCTION); // execute the Page Program instruction

  // sends the start reading address, Address_MSB first
  for(i = 2; i>= 0; i--){

    dummy = SPI_BB(_readAddress[i]);

  }

  for(i = 0; i<1024; i++){

    _readData[i] = SPI_BB(dummy);

  }

  digitalWrite(DMCS,HIGH); // resets the slave to disabled mode


}



/*******   END    ********
****   Memory Read    **** 
*************************/



/* -#-#--#-#--#-#--#-#--#-#--#-#--#-#--#-#--#-#--#-#--#-#--#-#--#-#--#-#--#-#--#-#--#-#--#-#--#-#--#-#--#-#--#-#- */



/*************************
****  Memory Erase    **** 
*************************/
// Erases the entire Data Memory
void Memory_Erase(void){


  byte WREN = 0x06; // Write enable instruction (06h)

  byte dummy = 0; // dummy byte var as the Writing process doesn't return any data

  byte ERASE_INSTRUCTION = 0xC7; // Page Program instruction 

  dummy = 0; // 


  // Write Enable command:
  digitalWrite(DMCS,LOW); // sets the slave to active mode
  digitalWrite(DMCLK,LOW); // initialize SCLK at idle state
  delayMicroseconds(Half_SPI_Period); // COM delay for half of a period
  dummy = SPI_BB(WREN); // execute the Write Enable instruction
  digitalWrite(DMCS,HIGH); // resets the slave to disabled mode
  delayMicroseconds(50); // 50us delay so the Erase Chip command can be accurately interpreted after the WREN instruction


  digitalWrite(DMCS,LOW); // sets the slave to active mode
  digitalWrite(DMCLK,LOW); // initialize SCLK at idle state
  delayMicroseconds(Half_SPI_Period); // COM delay for half of a period
  dummy = SPI_BB(ERASE_INSTRUCTION); // execute the Page Program instruction
  digitalWrite(DMCS,HIGH); // // resets the slave to disabled mode


}



/*******   END   ********
****  Memory Erase    **** 
*************************/





/* -#-#--#-#--#-#--#-#--#-#--#-#--#-#--#-#--#-#--#-#--#-#--#-#--#-#--#-#--#-#--#-#--#-#--#-#--#-#--#-#--#-#--#-#- */



/************************
****    Temp Read    **** 
*************************/
// Makes the reading of 256 stable temperature values to be stored on a data memory page
// Stabilizes the instantaneous temperature read using a Moving Average Filter
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

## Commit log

2023-05-11 :memo: add restante dos data sheets (Atmega328P-A eh muito grande pra subir)
    [ESP8266_Pin_List_0.xls]
2023-05-14 1 - :fire: | 2 -:memo: | 1 - Remocao dos circuitos p/ Atmega328P-A e Alimentacao Rede | 2 - Add Data Sheet AMS1117
    [fullWirelessComTractian.kicad_pcb, fullWirelessComTractian.kicad_sch]
2023-05-14 :arrow_up: Modificacao da PCB para 4-layers
    [fullWirelessComTractian.kicad_pcb]
2023-05-14 :construction: Add GND Mounting Holes and PCB borders
    [fullWirelessComTractian.kicad_pcb]
2023-05-14 :construction: Arranjo dos componentes | destaque para o circuito pi e XTAL em 0.8mm
    [fullWirelessComTractian.kicad_pcb, fullWirelessComTractian.kicad_sch]
2023-05-14 :construction: Schematics reorganizado | definicao de trail mils para power/GND lines e signal lines
    [fullWirelessComTractian.kicad_pcb, fullWirelessComTractian.kicad_sch]
2023-05-15 1 - :boom: | 2 - :memo: | 1- Calculo e projeto da impedancia de 50ohms para a antena RF | 2 - add datasheet antena RTexasSWRA117D 2.4GHz
    [fullWirelessComTractian.kicad_pcb, fullWirelessComTractian.kicad_sch]
2023-05-15 :construction: Nova organizacao da PCB | Routing in progress
    [fullWirelessComTractian.kicad_pcb, fullWirelessComTractian.kicad_sch]
2023-05-15 :heavy_plus_sign: Add circuito TMP36 Temp Sensor
2023-05-16 :construction: PCB Routes Finished | PCB Borders defined | ANT1 track drawn manually (error ignore on no net connection for ANT1)
    [fullWirelessComTractian.kicad_pcb, fullWirelessComTractian.kicad_sch]
2023-05-16 :construction: Add tantos GND vias quanto possível para melhor aterramento - RF design ESP datasheet
    [fullWirelessComTractian.kicad_pcb]
2023-05-16 1 - :rocket: | 2 :memo: | 1 - Final PCB and Gerbers | 2 - Add doc TMP36
    [fullWirelessComTractian-B_Mask.gbr, fullWirelessComTractian-B_Paste.gbr, fullWirelessComTractian-B_Silkscreen.gbr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]
2023-05-16 :tada: Add do arquivo do firmware - Descricao do Firmware e inicio da subrotina do bit banging SPI -IDE do Arduino
2023-05-16 :rocket: Bit banging SPI subroutine and pre definitions
2023-05-16 :bug: fix da Read subroutine
    [fullWirelessComTractian.kicad_pcb, fullWirelessComTractian.kicad_sch]
2023-05-17 :rocket: Rotina de leitura de temperatura com estabilizacao por filtro LTI media movel
    [fullWirelessComTractian.kicad_sch]
2023-05-17 1 - :rocket: | 2 - :rocket: - 1 - Erase Chip routine | 2 - Temperatue Collect, Write on Data Memory on main loop
2023-05-17 :rocket: Read (right this time) 1024 bytes of data Function
    [fullWirelessComTractian.kicad_pcb, fullWirelessComTractian.kicad_sch]
2023-05-18 :memo: Updates on the documentation | Preliminares, Introduction and Part of Schematics and PCB Design
    [fullWirelessComTractian.kicad_pcb, fullWirelessComTractian.kicad_sch]
2023-05-19 :memo: Updates on the documentation | Preliminares, Introduction, Schematics and PCB Design completed
